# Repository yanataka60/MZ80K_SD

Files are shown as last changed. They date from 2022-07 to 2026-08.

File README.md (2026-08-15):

# MZ-80シリーズにSD-Cardとのロード、セーブ機能を

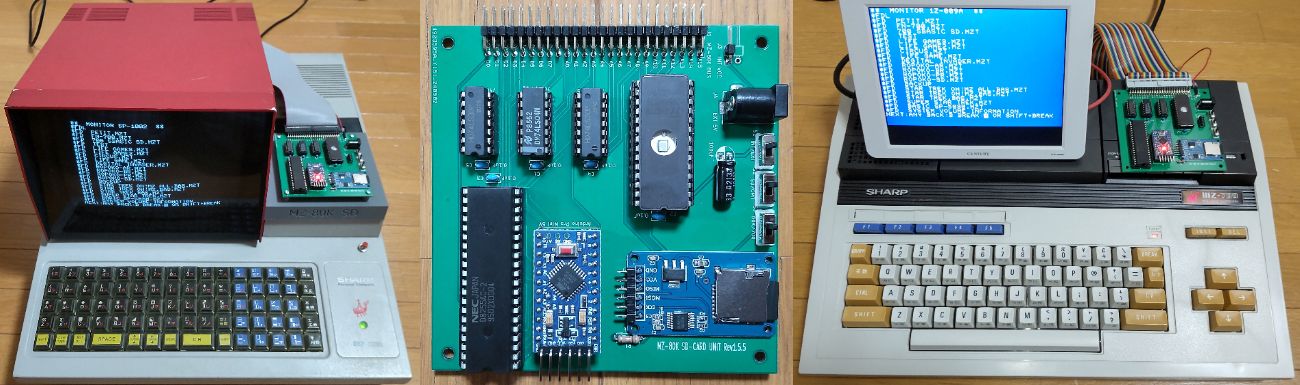
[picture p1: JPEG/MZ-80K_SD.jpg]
MZ-80K_SD


　ROMをF000Hに置くことでMZ-80シリーズにフロッピーディスク装置を外付けした際に起動するためのFDコマンドを利用できますが、フロッピーディスク装置の代わりにSD-CARDを繋いでしまおうというものです。

#### 　2025.7.31追記 MZ-80K、MZ-80K2、MZ-80K2E、MZ-80C、MZ-1200、MZ-700で動作しますが、MZ-700はRAMとの切替動作をサポートしたMZ-700_SDもあります。

　アダプタを繋ぐだけでもBASIC SP-5030が約4秒で起動できるようになるなどアプリケーションランチャーとして便利に使えますが、MONITOR SP-1002にパッチをあてることでBASIC SP-5030はもちろん、ほとんどのMZ-80KアプリケーションがSD-CARD対応となります。

### 本体ROMをパッチを当てたMONITOR SP-1002に交換しなくてもアプリケーションからのロード、セーブをSD対応とさせるパッチあてWindows用ツール「CMT2SD_CHECK」を公開しました。(2022.6.29)
### 詳細は、CMT2SD_CHECKフォルダ中のREADME.mdを参照してください。

　MZ-700もMZ-80K用アプリケーションについては同様にSD-CARD対応となりますが、標準添付のS-BASIC、Hu-BASICともMONITOR 1Z-009A、1Z-009BのCMTルーチンを利用していないためMONITOR 1Z-009A、1Z-009BにパッチをあてただけではSD-CARD対応となりません。

　S-BASICについてはパッチを当てることでSD-CARD対応となりますが、Hu-BASICは未対応です。

　基本的にはMZ-700ではMZ-80K互換機として利用できると考えてください。

　また、MZ-700もFDxコマンドは機能しますのでMZ-700用アプリケーションランチャーとして使えますが、MZ-80K対応とうたっていない64KオールRAMを前提としているMZ-700用アプリケーションはロードできない可能性があります。

　MZ-700+MZ-80K_SDでMZ-700用アプリケーションを実行したときにMZ-80K_SDのROMとMZ-700本体のRAMが衝突しないよう「ROM切り離しスイッチ」を取り入れましたが、これを自動で行うMZ-700_SD基板も公開しています。ただし、MZ-700_SDを作成するにはGAL16V8の入手が必要です。

　なお、一部のMZ-80K用ソフトはMZ-700で実行するにあたって、0h!MZ別冊 ADVANCED MZ-700に掲載されているSP-1002のMZ-700対応版 NZ-700が必要となるものがあります。

https://github.com/yanataka60/MZ-700_SD

#### 注）

　一応安定動作を確認していますが、SAVE動作によりSD-CARDに保存されたデータファイルの消失等考えられますのでファイルのバックアップをお願いします。

　Arduino、ROMへ書き込むための機器が別途必要となります。

### (2026.8.13追記)すねいるさんのBARYONに対応するためArduinoプログラムを更新しました。また、ROMプログラムも合わせて更新することで多段ロードにも対応します。

### 多段ロードの詳細については後述「BARYON対応」「多段ロード対応」を参照してください。

BARYON対応:https://github.com/yanataka60/MZ80K_SD#baryon%E5%AF%BE%E5%BF%9C2026813

多段ロード対応:https://github.com/yanataka60/MZ80K_SD#%E5%A4%9A%E6%AE%B5%E3%83%AD%E3%83%BC%E3%83%89%E5%AF%BE%E5%BF%9C2026813

## 回路図
　KiCadフォルダ内のMZ80K_SD.pdf参照

[回路図](https://github.com/yanataka60/MZ80K_SD/blob/main/KiCad/MZ80k_SD/MZ80K_SD.pdf)
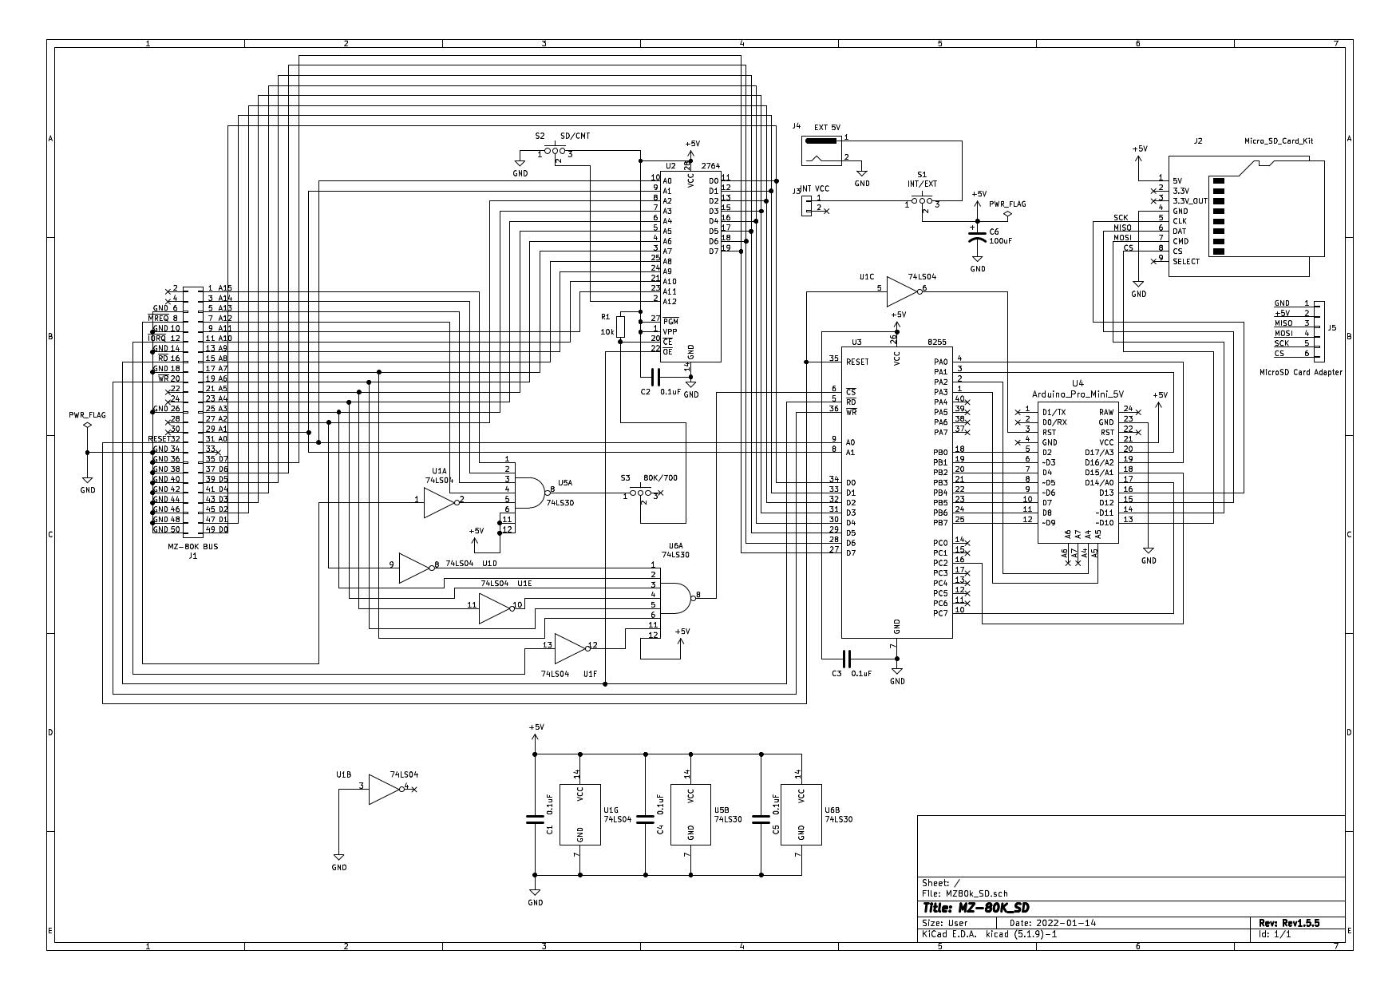
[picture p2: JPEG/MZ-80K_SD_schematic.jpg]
回路図


## 部品
|番号|品名|数量|備考|
| --- | --- | --- | --- |
|U1|74LS04|1||
|U2|2764又は28C64|1|ROMの相性については後述|
|U3|8255|1||
|U4|Arduino_Pro_Mini_5V|1|Atmega328版を使用 168版は不可。(注1)|
|U5 U6|74LS30|2||
||J2、J5のいづれか|||
|J2|Micro SD Card Kit又は同等品|1|秋月電子通商 AE-microSD-LLCNV (注2) (注3)|
|J5|MicroSD Card Adapter|1|Arduino等に使われる5V電源に対応したもの (注3)|
|C1-C5|積層セラミックコンデンサ 0.1uF|5||
|C6|電解コンデンサ 16v100uF|1||
|S1 S2|3Pスライドスイッチ|2|秋月電子通商 SS12D01G4など|
|S3|3Pスライドスイッチ|1|MZ-700で使わなければ80K側固定のジャンパでも可|
|R1|カーボン抵抗 10kΩ|1|S3を使わずに80K側固定でジャンパするなら不要|
|J4|DCジャック|1||
|J3|コネクタ 2Pin|1|ピンヘッダで代用するときはGNDと間違えないよう1Pinで5Vだけにしたほうが良い|
|J1|50Pinコネクタ|1||
||50Pinケーブル|1||
||ピンヘッダ|2Pin分|Arduino_Pro_MiniにはA4、A5用のピンヘッダが付いていないため別途調達が必要です 秋月電子通商 PH-1x40SGなど|
||本体内から5Vを取る場合、ケーブル少々|||
||本体ROMにパッチをあてる場合、27C32等を2532ソケットに差すためのアダプタ|||
||ピンソケット(任意)|26Pin分|Arduino_Pro_Miniを取り外し可能としたい場合に調達します 秋月電子通商 FHU-1x42SGなど|

　　　注1)Arduino Pro MiniはA4、A5ピンも使っています。

　　　注2)秋月電子通商　AE-microSD-LLCNVのJ1ジャンパはショートしてください。

　　　注3)J2又はJ5のどちらかを選択して取り付けてください。

### MicroSD Card Adapterを使う
J5に取り付けます。

MicroSD Card Adapterについているピンヘッダを除去してハンダ付けするのが一番確実ですが、J5の穴にMicroSD Card Adapterをぴったりと押しつけ、裏から多めにハンダを流し込むことでハンダ付けをする方法もあります。なお、この方法の時にはしっかりハンダ付けが出来たかテスターで導通を確認しておいた方が安心です。

ハンダ付けに自信のない方はJ2の秋月電子通商　AE-microSD-LLCNVをお使いください。AE-microSD-LLCNVならパワーLED、アクセスLEDが付いています。

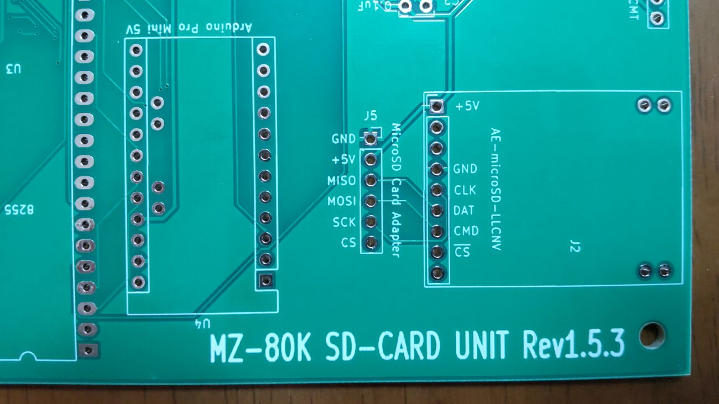
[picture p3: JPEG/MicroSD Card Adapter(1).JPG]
MicroSD Card Adapter1


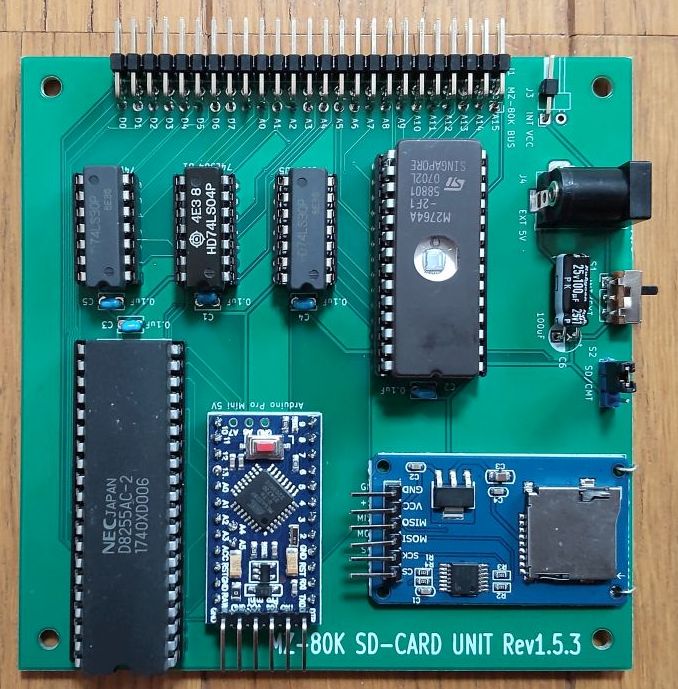
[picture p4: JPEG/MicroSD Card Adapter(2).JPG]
MicroSD Card Adapter2


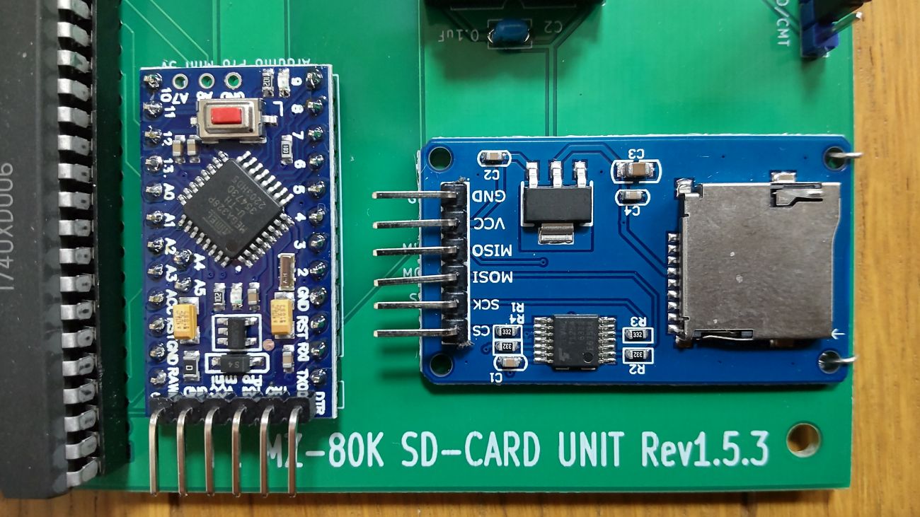
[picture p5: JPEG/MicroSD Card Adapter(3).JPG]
MicroSD Card Adapter3


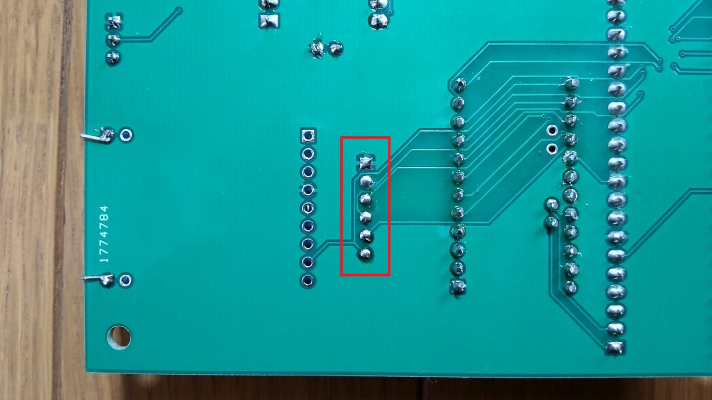
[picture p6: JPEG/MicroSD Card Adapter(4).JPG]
MicroSD Card Adapter4


## ROMプログラムについて
　Z80フォルダ内にFD_rom1.bin、FD_rom2.bin、FD_rom.binと3つありますが、SD-CARDを利用するためのプログラムFD_rom1.bin(28C64の下位に配置)、MONITORをCMT利用に戻すためのプログラムFD_rom2.bin(28C64の上位に配置)、2つを合わせたプログラムFD_rom.binとなっています。

　ROMライター(TL866II Plus等)を使って2764又は28C64にFD_rom.binを書き込んでください。

　28C64にFD_rom.binを書き込むことでスライドスイッチによりSDとCMTを切り替えられるようにしてあります。

　ただし、稼働中に切り替えるとタイミングによってはMZ-80Kが暴走する時があります。基本的には電源を切って切り替えてください。

　また、FD_rom2の領域には4023Byte分の空きエリアがあります。自由に使っていただいて構いません。

　なお、MZ-700でMONITOR 1Z-009A、1Z-009BにMZ-80K_SD用のパッチをあてた状態でもCMT側に切り替えれば紅茶羊羹さんの「MZ⇔PC間でデータを転送する（USB版）」が問題なく使用できます。

## ROMの相性
　すべての状況をテストできたわけではないのですが、ROMの個体によっては相性があるのではないかとの報告があります。

　特に問題なく動いているROMと動かない個体の例が報告されているROMを以下に列挙します。

　これからROMを調達される方はなるべく「特に問題なく動いているROM」を調達したほうが無難だと思われます。

|特に問題なく動いているROM|
| ----------------------- |
|AT28C64B                 |
|CAT28C64BP               |
|M2764A                   |

|動かない個体の例が報告されているROM|
| --------------------------------- |
|HN484764G                          |
|M27C64A                            |
|TMM2764D                           |
|TMS2764                            |
|D28C64ACZ                          |

## Arduinoプログラム
　Arduino IDEを使ってArduinoフォルダ内のMZ-80K_SD.inoを書き込みます。

　SdFatライブラリを使用していますのでArduino IDEメニューのライブラリの管理からライブラリマネージャを立ち上げて「SdFat」をインストールしてください。

　「SdFat」で検索すれば見つかります。「SdFat」と「SdFat - Adafruit Fork」が見つかりますが「SdFat」のほうを使っています。

注)Arduinoを基板に直付けしている場合、Arduinoプログラムを書き込むときは、MZ-80K本体とは接続を外し、74LS04を外したうえで書き込んでください。

## MZ-80Kとの接続
　回路図J1のピン番号とMZ-80K外部拡張端子のピン番号は一致していません。ピン配置は一致していますのでJPGフォルダにある「Rev1.5.1+MZ-80K Series(6).JPG」を参考にフラットケーブルで接続してください。

　MZ-700の外部拡張端子はMZ-80Kとピン配置は同じですが、ピンコネクタではなく、カードエッジコネクタです。

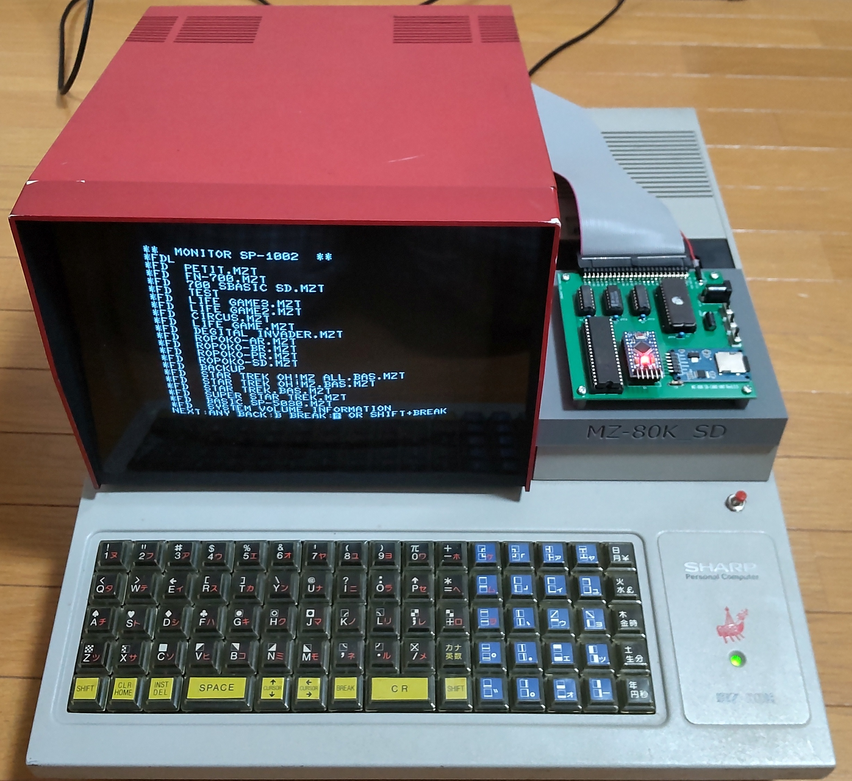
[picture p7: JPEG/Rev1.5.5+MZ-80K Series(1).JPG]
接続1


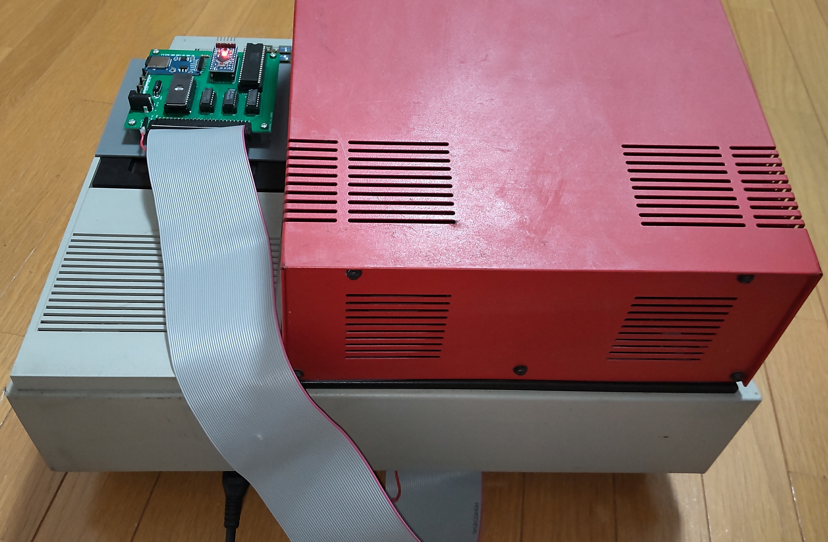
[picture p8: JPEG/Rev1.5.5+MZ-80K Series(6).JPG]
接続2


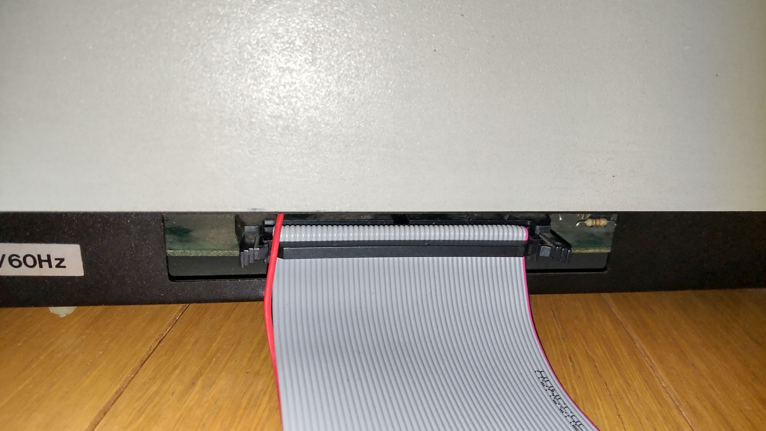
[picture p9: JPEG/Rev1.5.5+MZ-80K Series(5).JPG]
接続3


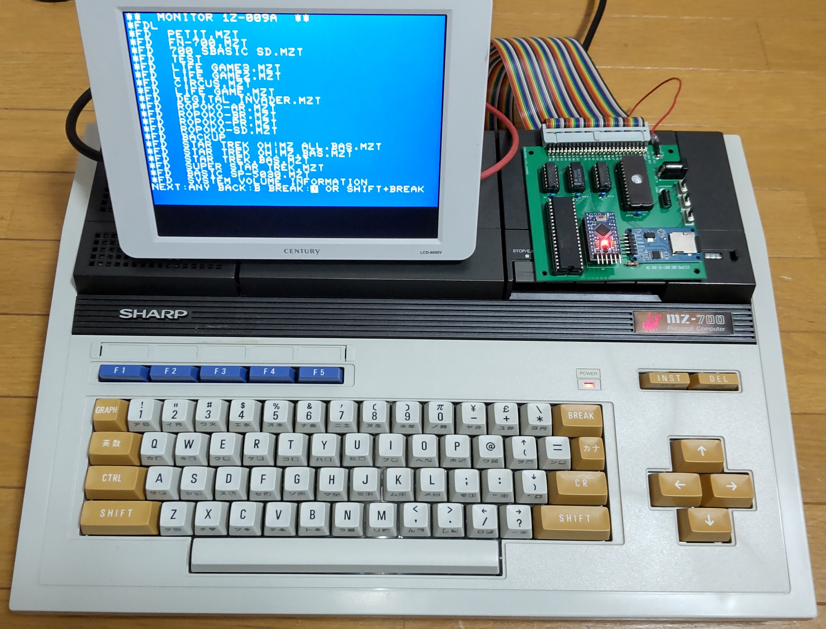
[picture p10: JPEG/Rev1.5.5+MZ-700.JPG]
接続4


## 電源
　MZ-80Kのバスには+5Vが出ていないため、最初はDCジャックから外部電源を供給するつもりだったのですが、本体と電源が一緒のほうが扱いが楽そうだったので本体から+5Vを引き出して供給する用のコネクタと二通りを用意しています。

　MZ-80K内部から5Vを取得するには、27C32等を2532ソケットに差すためのアダプタから引っ張ってくるのが簡単だと思います。

## MONITOR ROMの差し替え
　MONITOR SP-1002、MONITOR 1Z-009A、1Z-009Bとも以下のパッチをあててください。

　0437 : D5 → C3

　0438 : C5 → 04

　0439 : E5 → F0

　0476 : D5 → C3

　0477 : C5 → 07

　0478 : E5 → F0

　04D9 : D5 → C3

　04DA : C5 → 0A

　04DB : E5 → F0

　04F9 : D5 → C3

　04FA : C5 → 0D

　04FB : E5 → F0

　0589 : D5 → C3

　058A : C5 → 10

　058B : E5 → F0

　MZ-700 MONITOR 1Z-009A、1Z-009Bについては、RAMにコピーしたMONITORにパッチを当てることでパッチを当てたROMに差し替えなくても済むように「FT.MZT」を作成しました。

　「FT.MZT」をSD-CARDのルートに置き、FD FT[CR]を実行することでRAM MONITORに制御が移ります。

　「FT.MZT」と同等の動作をするFDZコマンドを新設しました。FDZコマンドを使えば「FT.MZT」は必要ありません。

　また、紅茶羊羹さんの「MZ⇔PC間でデータを転送する（USB版）」でMZTrans用パッチをMONITOR 1Z-009A、1Z-009Bに当てているとFコマンドが使えないので以下のパッチを当てることで'#'コマンドをつぶして'F'コマンドを復活させます。

　00D2 : 23 → 46

　00D4 : 86 → 21

　紅茶羊羹さん作成の「TR.MZT」をSD-CARDのルートに置き、「FD TR」を実行することでMZTransを使う方法もあります。

## BASIC SP-5030 バージョン違い

　BASIC SP-5030には、旧・新・VER1.0Aの３種類のバージョンがあるそうで、そのうち新・VER1.0Aの二つはパッチをあてる必要があります。以下のアドレスが4049H、4069Hを指している場合には新・VER1.0Aのどちらかですので以下のように修正する必要があります。

アドレスはMZTファイルのアドレスです。実アドレスは()内

　18C5(1845) : 49 → 27

　18C6(1846) : 40 → 00

　1939(18B9) : 69 → 2A

　193A(18BA) : 40 → 00

　19EA(196A) : 69 → 2A

　19EB(196B) : 40 → 00

　1AE0(1A60) : 69 → 2A

　1AE1(1A60) : 40 → 00

## SD-CARD
　出来れば8GB以下のSDカードを用意してください。

　ArduinoのSdFatライブラリは、SD規格(最大2GB)、SDHC規格(2GB～32GB)に対応していますが、SDXC規格(32GB～2TB)には対応していません。

　また、SDHC規格のSDカードであっても32GB、16GBは相性により動作しないものがあるようです。

　FAT16又はFAT32が認識できます。NTFSは認識できません。

　ルートに置かれたMZTファイルのみ認識できます。(MZT以外のファイル、フォルダも表示されますがLOAD実行の対象になりません)

　ファイル名は「.MZT」を除いて32文字まで、ただし半角カタカナ、及び一部の記号はArduinoが認識しないので使えません。パソコンでファイル名を付けるときはアルファベット、数字および空白でファイル名をつけてください。

## 操作方法
　MONITORコマンド入力待ちから以下のコマンドが利用できます。

　なお、MZ-700のフロッピーディスク装置起動コマンドは本来'F'の一文字ですが、操作方法としては'FD'に統一しました。

　以下、SD-CARD内のファイルに付けられるファイル名をDOSファイル名、MZT形式ファイルのインフォメーションブロック内ファイル名をIBFファイル名とします。

### FD[CR]
　FDのみでDOSファイル名「0000.MZT」がLOAD及び実行されます。

　「0000.MZT」は、パソコンでBASIC SP-5030等をリネームコピーして作成しても大丈夫ですが、FDAコマンドから作ることもできます。

### FD　DOSファイル名[CR]
　DOSファイル名で指定したバイナリファイルをLOADして実行します。

　「.MZT」は省略可能です。

　MONITORのLOADコマンドの代替として使えます。なお、LOADコマンドも使えますが、アプリケーションからのLOADと同じ扱いになります。

例)

FD　TEST[CR]

### FD/DOSファイル名[CR] 又は FD/　DOSファイル名[CR]
　DOSファイル名で指定したバイナリファイルをLOADします。実行はしません。

　「.MZT」は省略可能です。

例)

FD/TEST[CR]

FD/　TEST[CR]

### FDL[CR]
　SD-CARDルートディレクトリにあるファイルの一覧を表示します。20件表示したところで指示待ちになるので打ち切るならSHIFT+BREAK又は↑を入力すると打ち切られ、Bキーで前の20件に戻ります。それ以外のキーで次の20件を表示します。

　行頭に「*FD」を付加して表示してあるので実行したいファイルにカーソルキーを合わせて[CR]キーを押すだけでLOAD、実行が可能です。

　表示される順番は、登録順となりファイル名アルファベッド順などのソートした順で表示することはできません。

### FDL　x[CR]
ファイル名がxで始まるファイルの一覧を表示します。20件表示したところで指示待ちになるので打ち切るならSHIFT+BREAK又は↑を入力すると打ち切られ、Bキーで前の20件に戻ります。それ以外のキーで次の20件を表示します。

xはMZのキーボードから入力可能な32文字までの文字列です。(数字、記号、アルファベット)

例)

FDL S[CR]

FDL SP[CR]

FDL BASIC S[CR]

### FDA　DOSファイル名[CR]
　DOSファイル名で指定したファイルを「0000.MZT」という名前でリネームコピーします。

　FDLコマンドで表示されたファイル名をカーソルで選択し、行頭の「*FD」に「A」だけ付加して[CR]キーを押せば簡単です。

### FDS　SAVE開始アドレス　SAVE終了アドレス　実行開始アドレス　DOSファイル名[CR]
　SAVE開始アドレスからSAVE終了アドレスまでをDOSファイル名でSAVEします。

　SAVE開始アドレス、SAVE終了アドレス、実行開始アドレスは16進数4桁で指定します。DOSファイル名の「.MZT」は省略可能です。

例)

FDS　1200　2FFF　1200　TEST[CR]

### FDC　DOSファイル名[CR]
　DOSファイル名で指定したファイルをコピーします。

　FDLコマンドで表示されたファイル名をカーソルで選択し、行頭の「*FD」に「C」だけ付加して[CR]キーを押せば簡単です。

　DOSファイル名を入力し、[CR]キーを押すと「NEW NAME:」と聞いてくるので新しいDOSファイル名を入力して[CR]キーを押します。

　新しいDOSファイル名に既にあるDOSファイル名を指定するとコピーせずに中断します。

例)

FDC　TEST[CR]

NEW NAME:TEST2[CR]

### FDR　DOSファイル名[CR]
　DOSファイル名で指定したファイルをリネームします。

　FDLコマンドで表示されたファイル名をカーソルで選択し、行頭の「*FD」に「R」だけ付加して[CR]キーを押せば簡単です。

　DOSファイル名を入力し、[CR]キーを押すと「NEW NAME:」と聞いてくるので新しいDOSファイル名を入力して[CR]キーを押します。

　新しいDOSファイル名に既にあるDOSファイル名を指定するとリネームせずに中断します。

例)

FDR　TEST[CR]

NEW NAME:TEST2[CR]

### FDD　DOSファイル名[CR]
　DOSファイル名で指定したファイルを削除します。

　FDLコマンドで表示されたファイル名をカーソルで選択し、行頭の「*FD」に「D」だけ付加して[CR]キーを押せば簡単です。

　DOSファイル名を入力し、[CR]キーを押すと「FILE DELETE?(Y:OK ELSE:CANSEL)」と聞いてくるのでYを押せば削除されます。Y以外のキーを押すとキャンセルとなります。

### FDP　DOSファイル名[CR]
　DOSファイル名で指定したファイルの内容をDUMPします。

　FDLコマンドで表示されたファイル名をカーソルで選択し、行頭の「*FD」に「P」だけ付加して[CR]キーを押せば簡単です。

　DOSファイル名を入力し、[CR]キーを押すとファイルの内容を128Byteを一画面として表示します。

　一画面表示したところで「NEXT:ANY BACK:B BREAK:SHIFT+BREAK」と表示して指示待ちとなるのでBで前の128Byteを表示、SHIFT+BREAKで中止、それ以外のキーで次の128Byteの表示となります。

　ファイルサイズが128Byteで割り切れない場合には最後のページは128Byteに揃うまで00Hで埋められます。

　ファイル内容を書き換えることはできません。

### FDM　開始アドレス[CR]
　開始アドレスからMZ-80Kのメモリ内容を128Byteを一画面として表示します。

　一画面表示したところで「NEXT:ANY BACK:B BREAK:SHIFT+BREAK」と表示して指示待ちとなるのでBで前の128Byteを表示、SHIFT+BREAKで中止、それ以外のキーで次の128Byteの表示となります。

　一画面表示している途中でもSHIFT+BREAKでいつでも中止できます。

### FDW　開始アドレス　1Byte(16進2桁)データ[CR]
　開始アドレスから16進2桁データをMZ-80Kのメモリに書き込みます。

　開始アドレスに続けて16進2桁で書き込むデータを記述し[CR]キーを押します。データの区切りの空白は無視しますのであってもなくても構いません。

　16進2桁のByteデータは一行に収まる範囲なら何Byte分を続けても構いません。

　一行入力して[CR]キーを押すとデータが書き込まれ、次のアドレスが表示されるので続けてデータを入力していけます。

　また、アドレスを修正すれば戻って修正や離れたアドレスにデータを書き込むことも可能です。

　データの書き込みを止めるときは表示されたアドレスにデータを書かずに[CR]キーを押します。

　16進数以外を入力して[CR]キーを押した場合には16進数以外を入力した直前までの有効なデータを書き込み次のアドレスを表示します。

例)

*FDW　1200　01　02　03　04　05　06　07　08[CR]

*FDW　1200　0102030405060708[CR]

*FDW　1200[CR]　(止めるとき)

*FDW　1200　12　34　5/[CR]　(12　34まで書き込まれます)

### FDZ[CR]
　【MZ-700専用】MZ-700用に作成した「FT.MZT」と同等の動きをします。 MONITOR 1Z-009A又は1Z-009Bを裏RAMにコピーしたうえでパッチを当てた後、裏RAM上のMONITORがスタートします。

　MZ-80Kで実行してしまった場合には、RESET動作となります。

### FDU[CR]
　【MZ-700専用、裏RAM MONITORで運用中にRESETした場合に限る】裏RAMに切り替え裏RAMのMONITORをスタートさせます。

　注）裏RAMにMONITORが無い状態で実行すると暴走します。

　MZ-80Kで実行してしまった場合には、RESET動作となります。

### アプリケーションからのLOAD
　L、LOAD等アプリケーションが指定したコマンドの後ろにはIBFファイル名を指定可となっていますが、指定せずにL、LOAD等のコマンドのみで[CR]キーを押します。

　CMTの場合にはここでPLAYボタンを押すよう指示が出るところですが、「DOS FILE:」と表示して行入力待ちになっていますのでDOSファイル名を入力して[CR]キーを押します。この時、「.MZT」の入力は省略できます。

　DOSファイル名は「.MZT」を除いて32文字まで、ただし半角カタカナ、及び一部の記号はArduinoが認識しないので使えません。パソコンでファイル名を付けるときはアルファベット、数字および空白でファイル名をつけてください。

例)BASIC SP-5030では

× LOAD "TEST"[CR]

○ LOAD[CR]

　DOS FILE:TEST[CR]

○ LOAD[CR]

　DOS FILE:TEST.MZT[CR]

** 参考 **

　S-OS SWORDでの運用に当たっては起動直後に「DV S:」としてデバイスを各SYSTEMデバイスとしてください。

　FUZZY BASICだけかもしれませんが共通フォーマットデバイスのままだとLOADコマンドでIBFファイル名の省略ができませんでした。

#### LOAD時の特殊コマンド
　「DOS FILE:」と表示して行入力待ちになったときに以下の特殊コマンドが使用可能です。

##### *FDL[CR]
##### *FDL x[CR]
　MONITORコマンド入力待ちからのFDL、FDL xと全く同等のファイル一覧機能が使えます。

　検索結果の行頭には「DOS FILE:」を付加して表示してあるのでLOADしたいファイルにカーソルキーを合わせて[CR]キーを押すだけでLOADが可能です。

　「*FDL」で検索、カーソルで選んで読み込もうとした場合に「DOS FILE:」に戻ってしまうアプリケーションがありますが、再度カーソルを合わせて[CR]すれば読み込めます。

### アプリケーションからのSAVE
　CMTの時と同様にアプリケーションの指定する入力方法、ルールでファイル名等を入力して保存してください。

　ただし、半角カタカナはArduinoが認識できないため、使用できません。アルファベット、数字および空白で指定してください。

　SAVE時は、入力したファイル名がIBFファイル名、DOSファイル名の両方に適用されます。

　DOSファイル名としての「.MZT」は自動的に付加されます。

例)BASIC SP-5030では

○ SAVE "TEST"[CR]

## 操作上の注意
　~~「SD-CARD INITIALIZE ERROR」と表示されたときは、SD-CARDをいったん抜き再挿入したうえでArduinoをリセットしてください。~~

　~~SD-CARDにアクセスしていない時に電源が入ったままで SD-CARDを抜いた後、再挿入しSD-CARDにアクセスすると「SD-CARD INITIALIZE ERROR」となる場合があります。再挿入した場合にはSD-CARDにアクセスする前にArduinoを必ずリセットしてください。~~

　~~SD-CARDの抜き差しは電源を切った状態で行うほうがより確実です。~~

　(2024.3.10) SD-CARDにアクセスしていない時に電源が入ったままでSD-CARDを抜くと再度SD-CARDを挿入してもSD-CARDにアクセスできない問題を解消しました。(Arduinoを最新版に書き換えてください)

　再度SD-CARDを挿入した後、FDL、LOAD、SAVE等でSD-CARDに3回ほどアクセスすれば復旧します。

　SD-CARDへのセーブ時にDOSファイル名を指定せずに[CR]を押下してしまった場合、「.MZT」というDOSファイルが作成されてしまいます。この「.MZT」はアプリケーションからLOADする時にDOSファイル名を指定せずに[CR]を押下した場合に読み込まれることで不測の動作を起こす原因になりますので作成された場合には削除しておく方が無難です。

　なお、「.MZT」は現在FDR及びFDDコマンドでは認識できませんので、Windowsパソコンから消去してください。

## SD-CARDに読み書きできるかを試した結果

　読み書き出来たもの(アルファベット順)

　　BASE-80 Ver35【I/O 1981年4月号】

　　BASIC SP-5030(パッチあて必要なバージョンあり)

　　CAP-Xインタプリタ【I/O 1980年5月号】

　　EDASM V1.2B【Oh!MZ 1985年1月号】

　　FORM VER1.0(注3)【I/O 1980年6月号】

　　FORTRAN-MZ V.1【I/O 1981年1月号】

　　GAME-MZ80K V.1(注1)【ASCII 1979年10月号】

　　HU-BASIC V1.3

　　KM-BASIC ver 0.8.3-beta(注2)

　　LSIアセンブラ(注1)【【ASCII 1979年11月号】

　　M-FORTH/MZ V1.1(注1)【I/O 1981年3月号】

　　micro PASCAL-MZ VER 2.2【ASCII 1980年6月号】

　　MONIOS【月刊マイコン 1982年2月号】

　　PALL【I/O 1979年12月号】

　　S-OS SWORD(S-OS用アプリ含む)【Oh!MZ 1986年2月号】【再掲載 Oh!MZ 1987年3月号】

　　SELF RELOCATABLE DEBUGGER【I/O 1980年11月号】

　　SP-2101 Z80 ASSEMBLER

　　SP-2201 TEXT EDITOR

　　SP-2301 RELOCATE LOADER

　　SP-2401 SYMB DEBUGGER

　　TL/1(注1)(注3)【ASCII 1981年5月号】

　　TTL VERSION 1.1【Oh!MZ 1984年10月号】

　　WICS INTERPRETER VER 1.1(注3)【I/O 1981年10月号】

　　8080用テキスト・エディタ＆アセンブラ【I/O 1980年9月号】

　　マシン語モニタ【I/O 1979年10月号】【I/O合本 MZ-80活用研究】

　　整数型ベーシックコンパイラー for MZ-80K/C, MZ-1200(注1)(注3)【諏訪工房】

注1)このアプリケーションはMZ-700非対応です。MZ-700で動かすには、0h!MZ別冊 ADVANCED MZ-700に掲載されているSP-1002のMZ-700対応版 NZ-700が必要です。NZ-700にSP-1002と同じようにMZ-80K_SDのパッチをあてることでMZ-700でも同様にLOAD、SAVEが可能となります。

注2)SAVEコマンドでファイルネームは指定できないようです。SAVE[CR]で「KMB-FILE VER 1.0」のファイルネームで保存されました。

注3)LOADコマンドから「*FDL」で検索、カーソルで選んで読み込もうとした場合に「DOS FILE:」に戻ってしまいますが、再度カーソルを合わせて[CR]すれば読み込めます。

　読み書き出来なかったもの

　　EDAS FOR MZ-1200 VER 1.2【I/O 1982年11月号】

　　EXIT MONITOR【ASCII 1981年6月号】

## MZ700用プログラムで起動確認したもの
　　S-BASIC 1Z-007B(LOAD、SAVEもSD対応となるパッチを公開しました)

　　S-OS SWORD(MZ-700用SWORDでSD-CARD運用するにはMONITOR-ROMの書き換えが必要です。MONITOR-ROMを書き換えずに「FT.MZT」又はFDZコマンドを実行しても起動後のLOAD、SAVEはCMTとなります)

　　HUBASIC VERSION 2.0A(起動後のLOAD、SAVEはCMT)

　　tiny XEVIOUS mz-700

　　タイムシークレット(すべてのプログラムを別ファイルとして保存が必要)

　　タイムトンネル(すべてのプログラムを別ファイルとして保存が必要)

　　TS-700(「I/O別冊 WICS・BASEプログラム集」掲載、TS-700フォルダ参照)

　　SuperBASE-700(「I/O別冊 WICS・BASEプログラム集」掲載、TS-700フォルダ参照)

　　WICSインタプリタ、コンパイラ(「I/O別冊 WICS・BASEプログラム集」掲載、TS-700フォルダ参照)

なお、起動確認していないアプリケーションでも起動だけであればFDコマンドで起動できる可能性があります。

## 自作アプリケーションでMZ-80K_SDからLOADするDOSファイル名を指定したい場合
　MZ-80K用自作アプリケーションでMZ-80K_SDからデータ・機械語プログラム等のバイナリデータをLOADする処理を追加したい場合にはF00Ah(MLHED)をコールしてDOSファイル名を入力した後、F00Dh(MLDAT)をコールしてデータをロードとなり、DOSファイル名をアプリケーションの中で指定しておくことが出来ません。

　そこで以下の機械語をアプリケーションに組み込み、コールすることでアプリケーション内でDOSファイル名を指定することが可能です。

　その後、F00DHをコールすればSDからLOADが実行されます。

|コード|
| ------------ |
|MLHED:　　LD　　　DE,FNAME|
|　　　　　DI|
|　　　　　PUSH　　DE|
|　　　　　PUSH　　BC|
|　　　　　PUSH　　HL|
|　　　　　CALL　　F082H|
|　　　　　PUSH　　DE|
|　　　　　XOR　　　A|
|　　　　　LD　　　DE,0000H|
|　　　　　CALL　　0033H|
|　　　　　POP　　　DE|
|　　　　　JP　　　F85BH|
|FNAME:|
|　　　　　DB　　　'TEST',0DH|

#### BASIC SP-5030のプログラム中でMZ-80K_SDからLOADするDOSファイル名を指定したい場合
　BASIC SP-5030で使うときは以下の機械語を適当なアドレスに配置し、BASICから呼び出します。

　わずかな機械語ですのでBASICプログラム中にDATA文にしておき、LIMIT文で機械語領域を確保、READ文で読み込み、POKE文でメモリに書き込むようにすれば手軽です。

|コード|
| ------------ |
|MLHED:　　DI|
|　　　　　PUSH　　DE|
|　　　　　PUSH　　BC|
|　　　　　PUSH　　HL|
|　　　　　CALL　　F082H|
|　　　　　PUSH　　DE|
|　　　　　XOR　　　A|
|　　　　　LD　　　DE,0000H|
|　　　　　CALL　　0033H|
|　　　　　POP　　　DE|
|　　　　　JP　　　F85BH|

DATA 243,213,197,229,205,130,240,213,175,017,000,000,205,051,000,209

DATA 195,091,248

##### BASIC SP-5030からの呼び出し

|コード|備考|
| --- | --- |
|G＄="TEST"|DOSファイル名を表す文字列を文字列変数に代入|
|USR(＄C000,G＄)|機械語を配置したアドレスとDOSファイル名を表す文字列を代入した文字列変数を値としてUSR関数を実行(SP-5030の場合文字列関数に代入された文字列の最後に0Dhが入ってます)|
|USR(＄F00D)|SDからデータをLOAD|

#### MZ-700でDOSファイル名を指定したい場合
　MONITOR 1Z-009A(B)上で動くアプリケーションであればF000hからのROMにバンク切替(OUT (E3h),A)することを考慮すればMZ-80Kと同じように機械語をコールすることで指定できるようになるはずです。

　S-BASIC上でDOSファイル名を指定するにはバンク切替の他、文字列関数に代入された文字列の最後が00hで終わっていること、インフォメーションブロック(IFB)の位置もMONITOR 1Z-009A(B)とは違う等の差異を解決できる方以外はハードルが高いかもしれません。

## 専用トレイ
　カセット部に被せて使うMZ-80K_SD用トレイを公開しました。

https://yanataka.booth.pm/items/6058283

　MZ-1200用はこちらです。

https://yanataka.booth.pm/items/6069703

## BARYON対応(2026.8.13)
　MZ-700本体ROMにMZ-80K_SD(MZ-700_SD)用パッチを当てていなければBARYONの3分割mztファイル(baryon-1.mzt,baryon-2.mzt,baryon-3.mzt)で問題なく起動しますが、MZ-700本体ROMにMZ-80K_SD(MZ-700_SD)用パッチを当てていると異常動作により起動できません。

　これに対応するため、Arduinoプログラムを更新しましたので書き換えてください。

　これによりBARYON 3分割mztファイル(baryon-1.mzt,baryon-2.mzt,baryon-3.mzt)が正常に起動するようになります。

　また3つのmztファイルを連結したものとして提供されているbaryon.mztを「baryon$.mzt」とファイルネームの最後に「$」を付けることで起動できるようになりました。

## 多段ロード対応(2026.8.13)
　Arduino、ROMの両方を更新することで次の４種類の多段ロードに対応します。

　ただし、IPL.ROM内のCMTサービスルーチンをコールしていることが条件です。２段目以降のLOADにサービスルーチンをコールせず、独自プログラムで読み込むプログラムには対応できません。

### ①複数mztファイル連続読み込み
　連続して読み込ませたいmztファイルのファイル名の最後に#n(n=1～9)連続する数字を付加します。

例)

hoge#1.mzt

hoge#2.mzt

hoge#3.mzt

### ②連結mzt
　連続して読み込ませたいmztファイルを単純にマージしたmztファイルです。ファイル名の最後に#を付加してください。

例)

hoge#.mzt

### ③連続データブロック形式(IFB、DATA、DATA…)[ダミーヘッダ無]
　インフォーメションブロックに続き、複数のデータブロックが配置されたmztファイルです。実機CMTファイルで多段ロードに使用されることがある形式でダミーヘッダはありません。ファイル名に制限はありません。

例)

hoge.mzt

### ④連続データブロック形式(IFB、DATA、(IFB)、DATA…)[ダミーヘッダ有]
　インフォーメションブロックに続き、複数のデータブロックが配置されたmztファイルです。③の形式ですが、IFBがないと動作しないエミュレータ用にダミーヘッダが付加されたものです。③と区別するためにファイル名の最後に$を付加してください。

例)

hoge$.mzt

## 謝辞
　基板の作成に当たり以下のデータを使わせていただきました。ありがとうございました。

　Arduino Pro Mini

　　https://github.com/g200kg/kicad-lib-arduino

　AE-microSD-LLCNV

　　https://github.com/kuninet/PC-8001-SD-8kRAM

　MZ-700への対応に当たっては、紅茶羊羹様の「MZ⇔PC間でデータを転送する（USB版）」が非常に参考になりました。ありがとうございました。

　不安定動作の解消に以下の皆様にご協力とご助言をいただきました。ありがとうございました。(アルファベット順)

　　EIJ様

　　hlide fremen様

　　junk_suga様

　　retrogamer128様

　Arduino等に使われる5V電源に対応したMicroSD Card Adapterを使って作られた事例をご報告いただきました。ありがとうございました。

　　𝕊𝕖ñ𝕠𝕣 𝔼𝕤𝕥𝕖𝕓𝕒𝕟様

## 追記
2021.12.12

　MZ-700をMZ-80Kの代わりとして使うだけならNZ-700を最初に起動すればパッチを当てたROMを焼かなくてもいいんだと気づきました。FDコマンドでNZ-700が起動するようにすればMZ-700のほうがハードルが低いかもしれません。

2021.12.12

　MZ-700用に「FT.MZT」を作成しました。

2021.12.13

　KiCad\MZ80k_SDフォルダの回路図MZ80K_SD.pdfをRev1.1に更新

2021.12.13

　MZ-80KのS-OS SWORDでアプリケーションをLOADしようとしたとき、最初の一回だけはなぜかインフォメーションブロックの読み込みで止まってしまい、継続するためにはキーを一回押す必要がある原因は、FLGETのDEBUGにMZ-700用の修正もしてしまっていたせいでした。元に戻したところ無事解消。

2021.12.14

　S-BASICについてSD-CARD対応とするパッチを公開しました。

2021.12.18 2021.12.19 2021.12.21

　(MZ-80Kの電源状況によっては内部電源では動作不安定になることもあるようです。不安定な挙動がある場合には外部電源を試してください。)

　昨日追記した挙動不安定は電源のせいではなく、28C64がハズレあるいは個体差によりブラウン管の磁気の影響を受けていたためでした。

　28C64に個体差があるとは思われますが、それを吸収すべきプログラムにバグがあったので修正。

2021.12.20

　27C64に対応するためROMの1PinをVCCに接続し、基板をRev1.2としました。

2021.12.24

　安定性向上のためプルアップ抵抗を追加することにしました。回路図、基板データの検証が終わり次第公開を予定しています。また、エラー処理にバグがありましたのでこちらもテストが終わり次第公開したいと思います。

2021.12.26

　エラー処理のバグを修正。回路修正は後日。

2021.12.29

　MZ-700 MONITOR 1Z-009Aを入手し動作に支障がないことを確認しました。

2022.1.19

　GALが不安定動作の原因と思われるため、TTLで置き換えました。テスト環境では今のところ非常に安定しています。

　今まで不安定動作の要因と思われていた内部電源、外部電源、28C64の個体差、ブラウン管の磁気の影響、プルアップ抵抗等についてもTTLに置き換えたことで解消されています。

2022.1.23

　04D8H MONITOR リード インフォメーション代替処理のバグを修正。HU-BASIC V1.3、8080用テキスト・エディタ＆アセンブラのLOAD時に起こっていたエラーに対処。

2022.1.24

　SAVE時ファイルネームの後ろの空白に対処する処理をArduino側からMZ-80K側に変更。

　Arduinoの比較演算子の記述を見直し。

2022. 1.25

　0475H MONITOR ライト データ代替処理、04F8H MONITOR リード データ代替処理での8255初期化を廃止

　Arduino側での各コマンド受信時のdelay()を廃止

2022.1.26

　FDコマンドでロード可能なファイル種類コードは0x01のみとしていた制限を撤廃した

2022.1.28

　MZ-700用「FT.MZT」の動作をするFDZ、FDUコマンドを新設した。

2022.1.29

　特定環境下でLOAD、SAVEを行うとアプリケーションが固まってしまう原因のCMT代替処理RETURN時の割込み許可(EI)を削除。

　FDPコマンドで前ページに戻ると表示が乱れる場合がある症状を修正。

2022.1.30

　FDLコマンド仕様変更 FDL A～Zの場合、ファイル名先頭一文字を比較して一致したものだけを出力

2022.1.31

　FDLコマンド仕様変更 FDL nでのページ指定を廃止。FDL xでキーボードから入力可能なすべての文字で先頭一致とした。代わりにBキーで前の20件に戻れる機能を追加した。

　FDコマンド実行後アプリ動作が固まってしまう機械、アプリへの対処

2022.2.2

　DOSファイル名がアルファベット小文字でもFDL xで検索できるよう修正

2022.2.4

　ArduinoにMZ-1200対策

2022.2.9

　FDLコマンド仕様変更 FLD xの比較文字列を32文字以内とした。

2022.2.10

　ROMの相性について付記しました。

　アプリケーションのLOADコマンドの中でFDLコマンドが使える機能を実装しました。

2022.2.11

　アプリケーションのLOADコマンドの中でFDLコマンドが使える機能がMZ-700 MONITOR 1Z-009A、1Z-009B環境下では使えないバグを修正しました。

2022.2.15

　外部電源での起動に躓く場合の対処法を記載。

2022.2.26

　基板をRev1.5.2に更新。外部電源での稼働時において起動が躓く現象に対処。Rev1.5.1をRev1.5.2相当への改造方法を掲載。

2022.3.27

　基板のシルク印刷の向きを修正。

　アプリケーションからDOSファイル名を指定せずにSAVEしたときの挙動について追記。

2022.3.28

　誤字修正　誤「FDC及びFDDコマンド」 -> 正「FDR及びFDDコマンド」

2022.4.8

　Rev1.5.2基板でも機体によっては、電源ON時に起動に躓くことがあるようです。本体をリセットすることで解消できますが、気になる方はArduinoプログラム74行目の「delay(1000)」を「delay(1500)」ぐらいにしてみてください。

2022.4.24

　KiCad Libraryの定数を修正。

2022.5.31

　誤解を招く表現を修正

　修正前)DOSファイル名を指定せずに[CR]を押下してしまった場合、

　修正後)SD-CARDへのセーブ時にDOSファイル名を指定せずに[CR]を押下してしまった場合、

2022.6.29

　アプリケーションからのロード、セーブをSD対応とさせるパッチあてWindows用ツール「CMT2SD_CHECK」を公開しました。

　回路図にネットラベルを追加しました。

2022.6.30

　Z80フォルダの「FD_rom.BIN」を今回の「FD_rom.BIN」へ置き換えました。

　「CMT2SD_CHECK」によりパッチを当てたアプリケーションを使うときには新しい「FD_rom.BIN」への交換が必要です。

2022.8.4

　Arduinoを基板に直付けしている場合、Arduinoプログラムを書き込むときの注意点を書き加えました。

2022.9.11

　MicroSD Card Adapter用の端子を付加し、基板をRev1.5.3に更新。

2023.6.19

　MZ-2000_SDの起動方式追加によりArduinoプログラムを修正。MZ-80K_SDには影響なし。

2023.9.20

　「I/O別冊 WICS・BASEプログラム集」に掲載されているTS-700、SuperBASE-700、WICSインタプリタ、コンパイラへの対応を追加した。

2023.9.23

　Tookatoさんから報告のあった「D28C64ACZ」を動かない個体の例が報告されているROMのリストに追加しました。

2024.1.15

　SDカードは8GB以下が望ましいことを追記。

2024.3.4

　「自作アプリケーションでMZ-80K_SDからLOADするDOSファイル名を指定したい場合」を追記。

2024.3.10

　電源が入ったままでSD-CARDを抜くと再度SD-CARDを挿入してもSD-CARDにアクセスできない問題を解消した。

2024.7.29

　Tookato様作MZ-700用ロポコVersion 1.2.2をMZ-80K_SD対応とするパッチを公開しました。

2024.7.31

　MZ-700用ロポコVersion 1.2.2をMZ-80K_SD対応とするパッチをMZ-1500_SD共用にしました。

2024.8.2

　Tookato様からご指摘により、MZ-700+MZ-80K_SDでロポコを遊ぶとき、SDから起動後にS2スイッチをSDからCMTに切り替える必要があることを追記しました。

2024.8.8

　ROM切り離しスイッチの増設方法を追加しました。

2024.9.1

　専用トレイを公開しました。

2024.10.10

　ROM切り離しスイッチを標準装備としたRev1.5.5基板及び自動切り替えとしたMZ-700_SDの記述を加えました。

2025.7.31

　MZ-80シリーズでの動作について追記。

2025.12.4

　kuran_kuranさんにArduinoプログラムのバグを発見していただきました。精査した結果、不要な処理が含まれていることが原因であったため不要な処理部分を削除しました。なお、未修正のままでも実害はありません。kuran_kuranさん、ありがとうございました。

2026.8.13

　BARYONに対応しました。

　retrogamer128さんの要望により多段ロードに対応しました。

2026.8.15

　旧基板用の記述を整理しました。ロポコがMZ-80K_SD、MZ-700_SD、MZ-1500_SDに正式対応となっていますので関連の記述を削除しました。

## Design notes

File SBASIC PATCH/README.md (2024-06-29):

# MZ-700 S-BASIC 1Z-007BをMZ-80K_SD対応にするパッチ

　S-BASIC 1Z-007BはMONITOR 1Z-009A、1Z-009Bをコールしていないため、MZ-80K_SD対応にするためにパッチを当てる必要があります。

　S-BASICの仕様を把握してはいないのですが、試行錯誤の末、一応正常にMZ-80K_SDが動いていると思われますので公開します。

　たまたま動いているだけかもしれませんのでバックアップをとってからの実行をお願いします。

#### 2023.2.24 本来80K用の回路ですのでMZ-700でRAMバンクが前に出た時にROMの出力と衝突します。このパッチをS-BASICに使用する場合はMZ-700本体にストレスがかかることを承知の上使用してください。

#### 2024.6.29 従来プロッタのCIRCLE命令をつぶしてSDアクセスルーチンを置いていましたが、未使用となっているキーワードテーブルの隙間に移動しました。これによりプロッタ関連命令もすべて使えるようになりました。

## パッチプログラムについて

　SBASIC_patch1.bin、SBASIC_patch2.binの二つをS-BASICのMZTファイルに当てます。

　MZTファイルの00A1Hから00AFHまで(実アドレス0021H～002FH)をSBASIC_patch1.binと差し替えます。

　MZTファイルの2E80Hから2FE3Hまで(実アドレス2E00H～2F63H)をSBASIC_patch2.binと差し替えます。

　~~MZTファイルの5184Hから52E7Hまで(実アドレス5104H～5267H)をSBASIC_patch2.binと差し替えます。~~

　パッチを当てたファイルを「S-BASIC SD.MZT」等パッチを当てたことが識別できるファイル名で保存してお使いください。

　~~プロッタのCIRCLE命令をつぶしています。プロッタの他の命令に影響があるか検証していませんが、プロッタ関連の命令は使えないとしてください。~~

## ファイル名について

　オリジナル通りに16文字までがファイル名となりますが、半角カナ文字はArduinoが認識できない、一部の記号はMZ-700のキーボードから入力できないので使えません。

　ロングファイルネームに対応できなかった引き換えにLOADコマンドもオリジナル通りの入力方法となり、そのままDOSファイル名となります。

例)

　SAVE "TEST.BAS" : TEST.BAS.MZTというDOSファイル名で保存されます。

　SAVE "TEST"     : TEST.MZTというDOSファイル名で保存されます。

　LOAD "TEST.BAS" : TEST.BAS.MZTというDOSファイル名のファイルがロードされます。

　LOAD "TEST"     : TEST.MZTというDOSファイル名のファイルがロードされます。

　DOSファイル名が「TEST SBASIC EIGHT.MZT」の場合、LOAD "TEST SBASIC EIGHT"と入力しても「TEST SBASIC EIGH.MZT」というDOSファイルを探しに行くためロードできません。

## 使用方法
　パッチを当てたS-BASIC.MZTをFDコマンドでロードします。MONITOR 1Z-009A、1Z-009Bにパッチを当てる必要はありませんので、FT.MZTの実行も不要です。

## 追記
2021.12.26

　エラー処理のバグを修正。

2024.6.29

　SDアクセスルーチンをキーワードテーブル隙間の未使用領域に移動。

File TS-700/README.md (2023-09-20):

# MZ-700 TS-700をMZ-80K_SD対応にするパッチ

　「I/O別冊 WICS・BASEプログラム集」に掲載されているTS-700はMONITOR 1Z-009A、1Z-009Bをコールしていないため、MZ-80K_SD対応にするためにパッチを当てる必要があります。

　TS-700をMZ-80K_SD対応とすることで同誌に掲載されているSuperBASE-700、WICSインタプリタ・コンパイラもMZ-80K_SD対応となります。

　MZ-80K_SDは、本来80K用の回路ですのでMZ-700でRAMバンクが前に出た時にROMの出力と衝突します。このパッチをTS-700に使用する場合はMZ-700本体にストレスがかかることを承知の上使用してください。

## パッチプログラムについて

　APP_TS-700.bin(1465Byte)をTS-700.bin又はTS-700.mztの直後に連結して保存します。

　TS-700.binは5632Byteで連結すると7097Byteになります。

　TS-700.mztなら128Byteのヘッダが付いていますので5760Byteで連結すると7225Byteになります

　TS-700.binならヘッダをつけてMZTファイルにします。

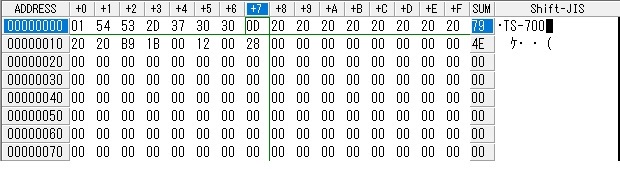
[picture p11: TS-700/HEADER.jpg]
Header


　TS-700.mztならファイルサイズと実行アドレスを修正します。

　TS-700起動時にSDアクセスルーチンは、F800h～に配置されます。BASE、WICSでプログラムを作るときにはF800h以降にオブジェクトを生成しないようにしてください。

## LOAD
　Lコマンドの後ろにはファイル名を指定せずに[CR]キーを押します。

　CMTの場合にはここでPLAYボタンを押すよう指示が出るところですが、「DOS FILE:」と表示して行入力待ちになっていますのでDOSファイル名を入力して[CR]キーを押します。この時、「.MZT」の入力は省略できます。

　DOSファイル名は「.MZT」を除いて32文字まで、ただし半角カタカナ、及び一部の記号はArduinoが認識しないので使えません。パソコンでファイル名を付けるときはアルファベット、数字および空白でファイル名をつけてください。

例)
× L TEST[CR]

○ L[CR]

　DOS FILE:TEST[CR]

### LOAD時の特殊コマンド
　「DOS FILE:」と表示して行入力待ちになったときに以下の特殊コマンドが使用可能です。

#### *FDL[CR]
#### *FDL x[CR]
　MONITORコマンド入力待ちからのFDL、FDL xと全く同等のファイル一覧機能が使えます。

　検索結果の行頭には「DOS FILE:」を付加して表示してあるのでLOADしたいファイルにカーソルキーを合わせて[CR]キーを押すだけでLOADが可能です。

　「*FDL」で検索、カーソルで選んで読み込もうとした場合に「DOS FILE:」に戻ってしまうアプリケーションがありますが、再度カーソルを合わせて[CR]すれば読み込めます。

## SAVE
　CMTの時と同様にアプリケーションの指定する入力方法、ルールでファイル名等を入力して保存してください。

　ただし、半角カタカナはArduinoが認識できないため、使用できません。アルファベット、数字および空白で指定してください。

　SAVE時は、入力したファイル名がIBFファイル名、DOSファイル名の両方に適用されます。

　DOSファイル名としての「.MZT」は自動的に付加されます。

例)

○ S8000,8FFF,8000,TEST[CR]

## BASE、WICSでのLOAD、SAVE

TS-700での扱いと同様にLOAD時にはファイル名を指定せずにDOS FILE:と聞かれたらDOSファイル名を指定します。

SAVEはBASE、WICSのSAVEの仕方と同様です。半角カタカナは使えません。入力したファイル名はIBFファイル名、DOSファイル名の両方に適用されます。

　DOSファイル名としての「.MZT」は自動的に付加されます。

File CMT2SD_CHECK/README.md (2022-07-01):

# アプリケーションからのロード、セーブをSD対応とさせるパッチあてWindows用ツール「CMT2SD_CHECK」

　MZ-80K_SDアダプタを繋ぐだけでもBASIC SP-5030が約4秒で起動できるようになるなどアプリケーションランチャーとして便利に使えますが、今まではMONITOR SP-1002にパッチをあてることを前提としていたためMONITOR ROMを交換しないとBASIC SP-5030等アプリケーションの起動はSDからできてもアプリケーションからのロード、セーブはCMTからとなってしまいます。

　そこでROMはそのままにしてアプリケーション側にSD対応パッチを当てるツールを作ってみました。

## CMT2SD_CHECKの使い方

　デスクトップ等適当な場所に「CMT2SD_CHECK.EXE」をコピーしてダブルクリックで起動させてください。

　次にSD用パッチを当てたいMZTファイルをCMT2SD_CHECKにドラッグアンドドロップしてください。

　ドロップされたアプリケーションにMONITOR SP-1002のCMT関連ルーチンを呼び出していると思われるコードが発見された場合は、元のMZTファイルと同じフォルダに元のMZTファイルのファイルネームに「_SD」を付加したMZTファイルと変更箇所を保存したTXTファイルを作成します。

　ドロップされたアプリケーションにMONITOR SP-1002のCMT関連ルーチンを呼び出していると思われるコードが無い場合には、何も作成されません。

例)

　「BASIC SP-5030.mzt」をドラッグアンドドロップ

　　BASIC SP-5030_SD.mzt、BASIC SP-5030_SD.txtが作成される。

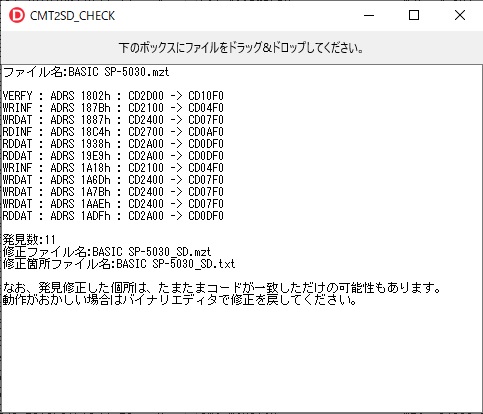
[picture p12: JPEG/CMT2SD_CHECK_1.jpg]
BASIC SP-5030


## 注意点
　「CMT2SD_CHECK.EXE」はMONITOR SP-1002のCMT関連ルーチンを呼び出していると思われるコードと一致した場合にパッチを当てますが、アプリケーションの中では命令コードではなくデータとして扱っているバイナリがたまたま一致した場合にもパッチを当ててしまいます。

　動作がおかしい場合には、変更箇所テキストファイルを参照して元に戻してください。

　また、コール命令(CD)、ジャンプ命令(C3)を使わずにCMT関連ルーチンを呼び出しているアプリケーションは検出できません。

## 「CMT2SD_CHECK.EXE」ソースコードについて
　「CMT2SD_CHECK.EXE」はDelphi 10.4Community Editionを使って作成しました。

　Pascalにしては拙いコードだとは思いますが、ご容赦願います。

## 追記
2022.6.30

　Z80フォルダの「FD_rom.BIN」を今回の「FD_rom.BIN」へ置き換えました。

　「CMT2SD_CHECK」によりパッチを当てたアプリケーションを使うときには新しい「FD_rom.BIN」への交換が必要です。

　CHECKの仕方を修正。機能に変更なし。

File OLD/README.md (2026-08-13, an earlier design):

# MZ-80シリーズにSD-Cardとのロード、セーブ機能を

MZ-80K_SD

　ROMをF000Hに置くことでMZ-80シリーズにフロッピーディスク装置を外付けした際に起動するためのFDコマンドを利用できますが、フロッピーディスク装置の代わりにSD-CARDを繋いでしまおうというものです。

#### 　2025.7.31追記 MZ-80K、MZ-80K2、MZ-80K2E、MZ-80C、MZ-1200、MZ-700で動作しますが、MZ-700はRAMとの切替動作をサポートしたMZ-700_SDもあります。

　アダプタを繋ぐだけでもBASIC SP-5030が約4秒で起動できるようになるなどアプリケーションランチャーとして便利に使えますが、MONITOR SP-1002にパッチをあてることでBASIC SP-5030はもちろん、ほとんどのMZ-80KアプリケーションがSD-CARD対応となります。

### 本体ROMをパッチを当てたMONITOR SP-1002に交換しなくてもアプリケーションからのロード、セーブをSD対応とさせるパッチあてWindows用ツール「CMT2SD_CHECK」を公開しました。(2022.6.29)
### 詳細は、CMT2SD_CHECKフォルダ中のREADME.mdを参照してください。

　MZ-700もMZ-80K用アプリケーションについては同様にSD-CARD対応となりますが、標準添付のS-BASIC、Hu-BASICともMONITOR 1Z-009A、1Z-009BのCMTルーチンを利用していないためMONITOR 1Z-009A、1Z-009BにパッチをあてただけではSD-CARD対応とならず、起動後はCMTでの運用となります。

#### (2021.12.14追記:S-BASICについてSD-CARD対応とするパッチを公開しました。)

#### (2024. 6.29追記:S-BASICについて従来プロッタのCIRCLE命令をつぶしてSDアクセスルーチンを置いていましたが、未使用となっているキーワードテーブルの隙間に移動しました。)

　基本的にはMZ-700ではMZ-80K互換機として利用できると考えてください。

　また、MZ-700もFDxコマンドは機能しますのでMZ-700用アプリケーションランチャーとして使えますが、MZ-80K対応とうたっていない64KオールRAMを前提としているMZ-700用アプリケーションはロードできない可能性があります。

　Rev1.5.5基板及びRev1.5.3基板で「ROM切り離しスイッチ改造」を行った方は、MZ-700用アプリケーション起動後はスイッチを「700」側に切り替えてください。再度SDから起動するときには「80K」に戻すのをお忘れなく。

　なお、一部のMZ-80K用ソフトはMZ-700で実行するにあたって、0h!MZ別冊 ADVANCED MZ-700に掲載されているSP-1002のMZ-700対応版 NZ-700が必要となるものがあります。

#### (2024.10.10追記:MZ-700+MZ-80K_SDでMZ-700用アプリケーションを実行したときにMZ-80K_SDのROMとMZ-700本体のRAMが衝突しないようRev1.5.5基板では「ROM切り離しスイッチ」を取り入れましたが、これを自動で行うMZ-700_SD基板も公開しています。ただし、MZ-700_SDを作成するにはGAL16V8の入手が必要です。

https://github.com/yanataka60/MZ-700_SD

#### 注）

　一応安定動作を確認していますが、SAVE動作によりSD-CARDに保存されたデータファイルの消失等考えられますのでファイルのバックアップをお願いします。

　Arduino、ROMへ書き込むための機器が別途必要となります。

### (2026.8.13追記)すねいるさんのBARYONに対応するためArduinoプログラムを更新しました。また、ROMプログラムも合わせて更新することで多段ロードにも対応します。

### 多段ロードの詳細については後述「BARYON対応」「多段ロード対応」を参照してください。

BARYON対応:https://github.com/yanataka60/MZ80K_SD#baryon%E5%AF%BE%E5%BF%9C2026813

多段ロード対応:https://github.com/yanataka60/MZ80K_SD#%E5%A4%9A%E6%AE%B5%E3%83%AD%E3%83%BC%E3%83%89%E5%AF%BE%E5%BF%9C2026813

## 回路図
　KiCadフォルダ内のMZ80K_SD.pdf参照

[回路図](https://github.com/yanataka60/MZ80K_SD/blob/main/KiCad/MZ80k_SD/MZ80K_SD.pdf)
回路図

　Rev1.5.5になりました。後述の「ROM切り離しスイッチ改造」を取り入れています。

　~~Rev1.5.3になりました。秋月電子通商　AE-microSD-LLCNVとArduino用Micro SD Card Kitのどちらかを選択して使えます。~~

　~~Rev1.5.2になりました。Rev1.5.1との違いは、外部電源での運用時にArduinoと本体の初期化のタイミングのズレにより誤動作してしまうことをArduinoのReset端子を本体のReset信号に接続し解消したことになります。~~

　~~なお、Rev1.5.1の1か所をパターンカットし、2本配線を追加することでRev1.5.2相当とする方法をKAIZOUフォルダに示しました。~~

## 部品
|番号|品名|数量|備考|
| --- | --- | --- | --- |
|U1|74LS04|1||
|U2|2764又は28C64|1|ROMの相性については後述|
|U3|8255|1||
|U4|Arduino_Pro_Mini_5V|1|Atmega328版を使用 168版は不可。(注1)|
|U5 U6|74LS30|2||
||J2、J5のいづれか|||
|J2|Micro SD Card Kit又は同等品|1|秋月電子通商 AE-microSD-LLCNV (注2) (注3)|
|J5|MicroSD Card Adapter|1|Arduino等に使われる5V電源に対応したもの (注3)|
|C1-C5|積層セラミックコンデンサ 0.1uF|5||
|C6|電解コンデンサ 16v100uF|1||
|S1 S2|3Pスライドスイッチ|2|秋月電子通商 SS12D01G4など|
|S3|3Pスライドスイッチ|1|MZ-700で使わなければ80K側固定のジャンパでも可|
|R1|カーボン抵抗 10kΩ|1|S3を使わずに80K側固定でジャンパするなら不要|
|J4|DCジャック|1||
|J3|コネクタ 2Pin|1|ピンヘッダで代用するときはGNDと間違えないよう1Pinで5Vだけにしたほうが良い|
|J1|50Pinコネクタ|1||
||50Pinケーブル|1||
||ピンヘッダ|2Pin分|Arduino_Pro_MiniにはA4、A5用のピンヘッダが付いていないため別途調達が必要です 秋月電子通商 PH-1x40SGなど|
||本体内から5Vを取る場合、ケーブル少々|||
||本体ROMにパッチをあてる場合、27C32等を2532ソケットに差すためのアダプタ|||
||ピンソケット(任意)|26Pin分|Arduino_Pro_Miniを取り外し可能としたい場合に調達します 秋月電子通商 FHU-1x42SGなど|

　　　注1)Arduino Pro MiniはA4、A5ピンも使っています。

　　　注2)秋月電子通商　AE-microSD-LLCNVのJ1ジャンパはショートしてください。

　　　注3)J2又はJ5のどちらかを選択して取り付けてください。

### MicroSD Card Adapterを使う(Rev1.5.3以降)
J5に取り付けます。

MicroSD Card Adapterについているピンヘッダを除去してハンダ付けするのが一番確実ですが、J5の穴にMicroSD Card Adapterをぴったりと押しつけ、裏から多めにハンダを流し込むことでハンダ付けをする方法もあります。なお、この方法の時にはしっかりハンダ付けが出来たかテスターで導通を確認しておいた方が安心です。

ハンダ付けに自信のない方はJ2の秋月電子通商　AE-microSD-LLCNVをお使いください。AE-microSD-LLCNVならパワーLED、アクセスLEDが付いています。

MicroSD Card Adapter1

MicroSD Card Adapter2

MicroSD Card Adapter3

MicroSD Card Adapter4

### MicroSD Card Adapterを使う(Rev1.5.2)
以下のピン番号を参考に変換基板等繋ぎ方は適宜対応してください。
|AE-microSD-LLCNVピン番号|MicroSD Card Adapterピン番号|信号名|
| --- | --- | ---- |
|1|2|5V|
|4|1|GND|
|5|5|SCK|
|6|3|MISO|
|7|4|MOSI|
|8|6|CS|

MicroSD Card Adapter

## ROMプログラムについて
　Z80フォルダ内にFD_rom1.bin、FD_rom2.bin、FD_rom.binと3つありますが、SD-CARDを利用するためのプログラムFD_rom1.bin(28C64の下位に配置)、MONITORをCMT利用に戻すためのプログラムFD_rom2.bin(28C64の上位に配置)、2つを合わせたプログラムFD_rom.binとなっています。

　ROMライター(TL866II Plus等)を使って2764又は28C64にFD_rom.binを書き込んでください。

　28C64にFD_rom.binを書き込むことでスライドスイッチによりSDとCMTを切り替えられるようにしてあります。

　ただし、稼働中に切り替えるとタイミングによってはMZ-80Kが暴走する時があります。基本的には電源を切って切り替えてください。

　また、FD_rom2の領域には4023Byte分の空きエリアがあります。自由に使っていただいて構いません。

　なお、MZ-700でMONITOR 1Z-009A、1Z-009BにMZ-80K_SD用のパッチをあてた状態でもCMT側に切り替えれば紅茶羊羹さんの「MZ⇔PC間でデータを転送する（USB版）」が問題なく使用できます。

## ROMの相性
　すべての状況をテストできたわけではないのですが、ROMの個体によっては相性があるのではないかとの報告があります。

　特に問題なく動いているROMと動かない個体の例が報告されているROMを以下に列挙します。

　これからROMを調達される方はなるべく「特に問題なく動いているROM」を調達したほうが無難だと思われます。

|特に問題なく動いているROM|
| ----------------------- |
|AT28C64B                 |
|CAT28C64BP               |
|M2764A                   |

|動かない個体の例が報告されているROM|
| --------------------------------- |
|HN484764G                          |
|M27C64A                            |
|TMM2764D                           |
|TMS2764                            |
|D28C64ACZ                          |

## Arduinoプログラム
　Arduino IDEを使ってArduinoフォルダ内のMZ-80K_SD.inoを書き込みます。

　SdFatライブラリを使用していますのでArduino IDEメニューのライブラリの管理からライブラリマネージャを立ち上げて「SdFat」をインストールしてください。

　「SdFat」で検索すれば見つかります。「SdFat」と「SdFat - Adafruit Fork」が見つかりますが「SdFat」のほうを使っています。

注)Arduinoを基板に直付けしている場合、Arduinoプログラムを書き込むときは、MZ-80K本体とは接続を外し、74LS04を外したうえで書き込んでください。

## MZ-80Kとの接続
　回路図J1のピン番号とMZ-80K外部拡張端子のピン番号は一致していません。ピン配置は一致していますのでJPGフォルダにある「Rev1.5.1+MZ-80K Series(6).JPG」を参考にフラットケーブルで接続してください。

　MZ-700の外部拡張端子はMZ-80Kとピン配置は同じですが、ピンコネクタではなく、カードエッジコネクタです。

接続1

接続2

接続3

接続4

## 電源
　MZ-80Kのバスには+5Vが出ていないため、最初はDCジャックから外部電源を供給するつもりだったのですが、本体と電源が一緒のほうが扱いが楽そうだったので本体から+5Vを引き出して供給する用のコネクタと二通りを用意しています。

　MZ-80K内部から5Vを取得するには、27C32等を2532ソケットに差すためのアダプタから引っ張ってくるのが簡単だと思います。

注)Rev1.5.1基板では、外部電源での稼働時に起動に躓くことがあるようです。内部電源での利用を推奨しますが、外部電源での稼働時にFDLコマンド等を実行しても反応が無い場合には次の手順で起動してください。

　　MZ-80K_SDの電源を入れる -> MZ-80Kの電源を入れる -> Arduinoをリセットする。

なお、Rev1.5.1基板に対して1か所をパターンカットし、2本配線を追加することでRev1.5.2基板相当とすることができます。詳しくはKAIZOUフォルダを参照してください。

　Rev1.5.2基板でも機体によっては、電源ON時に起動に躓くことがあるようです。本体をリセットすることで解消できますが、気になる方はArduinoプログラム74行目の「delay(1000)」を「delay(1500)」ぐらいにしてみてください。

## MONITOR ROMの差し替え
　MONITOR SP-1002、MONITOR 1Z-009A、1Z-009Bとも以下のパッチをあててください。

　0437 : D5 → C3

　0438 : C5 → 04

　0439 : E5 → F0

　0476 : D5 → C3

　0477 : C5 → 07

　0478 : E5 → F0

　04D9 : D5 → C3

　04DA : C5 → 0A

　04DB : E5 → F0

　04F9 : D5 → C3

　04FA : C5 → 0D

　04FB : E5 → F0

　0589 : D5 → C3

　058A : C5 → 10

　058B : E5 → F0

　MZ-700 MONITOR 1Z-009A、1Z-009Bについては、RAMにコピーしたMONITORにパッチを当てることでパッチを当てたROMに差し替えなくても済むように「FT.MZT」を作成しました。

　「FT.MZT」をSD-CARDのルートに置き、FD FT[CR]を実行することでRAM MONITORに制御が移ります。

　「FT.MZT」と同等の動作をするFDZコマンドを新設しました。FDZコマンドを使えば「FT.MZT」は必要ありません。

　また、紅茶羊羹さんの「MZ⇔PC間でデータを転送する（USB版）」でMZTrans用パッチをMONITOR 1Z-009A、1Z-009Bに当てているとFコマンドが使えないので以下のパッチを当てることで'#'コマンドをつぶして'F'コマンドを復活させます。

　00D2 : 23 → 46

　00D4 : 86 → 21

　紅茶羊羹さん作成の「TR.MZT」をSD-CARDのルートに置き、「FD TR」を実行することでMZTransを使う方法もあります。

## BASIC SP-5030 バージョン違い

　BASIC SP-5030には、旧・新・VER1.0Aの３種類のバージョンがあるそうで、そのうち新・VER1.0Aの二つはパッチをあてる必要があります。以下のアドレスが4049H、4069Hを指している場合には新・VER1.0Aのどちらかですので以下のように修正する必要があります。

アドレスはMZTファイルのアドレスです。実アドレスは()内

　18C5(1845) : 49 → 27

　18C6(1846) : 40 → 00

　1939(18B9) : 69 → 2A

　193A(18BA) : 40 → 00

　19EA(196A) : 69 → 2A

　19EB(196B) : 40 → 00

　1AE0(1A60) : 69 → 2A

　1AE1(1A60) : 40 → 00

## SD-CARD
　出来れば8GB以下のSDカードを用意してください。

　ArduinoのSdFatライブラリは、SD規格(最大2GB)、SDHC規格(2GB～32GB)に対応していますが、SDXC規格(32GB～2TB)には対応していません。

　また、SDHC規格のSDカードであっても32GB、16GBは相性により動作しないものがあるようです。

　FAT16又はFAT32が認識できます。NTFSは認識できません。

　ルートに置かれたMZTファイルのみ認識できます。(MZT以外のファイル、フォルダも表示されますがLOAD実行の対象になりません)

　ファイル名は「.MZT」を除いて32文字まで、ただし半角カタカナ、及び一部の記号はArduinoが認識しないので使えません。パソコンでファイル名を付けるときはアルファベット、数字および空白でファイル名をつけてください。

## 操作方法
　MONITORコマンド入力待ちから以下のコマンドが利用できます。

　なお、MZ-700のフロッピーディスク装置起動コマンドは本来'F'の一文字ですが、操作方法としては'FD'に統一しました。

　以下、SD-CARD内のファイルに付けられるファイル名をDOSファイル名、MZT形式ファイルのインフォメーションブロック内ファイル名をIBFファイル名とします。

### FD[CR]
　FDのみでDOSファイル名「0000.MZT」がLOAD及び実行されます。

　「0000.MZT」は、パソコンでBASIC SP-5030等をリネームコピーして作成しても大丈夫ですが、FDAコマンドから作ることもできます。

### FD　DOSファイル名[CR]
　DOSファイル名で指定したバイナリファイルをLOADして実行します。

　「.MZT」は省略可能です。

　MONITORのLOADコマンドの代替として使えます。なお、LOADコマンドも使えますが、アプリケーションからのLOADと同じ扱いになります。

例)

FD　TEST[CR]

### FD/DOSファイル名[CR] 又は FD/　DOSファイル名[CR]
　DOSファイル名で指定したバイナリファイルをLOADします。実行はしません。

　「.MZT」は省略可能です。

例)

FD/TEST[CR]

FD/　TEST[CR]

### FDL[CR]
　SD-CARDルートディレクトリにあるファイルの一覧を表示します。20件表示したところで指示待ちになるので打ち切るならSHIFT+BREAK又は↑を入力すると打ち切られ、Bキーで前の20件に戻ります。それ以外のキーで次の20件を表示します。

　行頭に「*FD」を付加して表示してあるので実行したいファイルにカーソルキーを合わせて[CR]キーを押すだけでLOAD、実行が可能です。

　表示される順番は、登録順となりファイル名アルファベッド順などのソートした順で表示することはできません。

### FDL　x[CR]
ファイル名がxで始まるファイルの一覧を表示します。20件表示したところで指示待ちになるので打ち切るならSHIFT+BREAK又は↑を入力すると打ち切られ、Bキーで前の20件に戻ります。それ以外のキーで次の20件を表示します。

xはMZのキーボードから入力可能な32文字までの文字列です。(数字、記号、アルファベット)

例)

FDL S[CR]

FDL SP[CR]

FDL BASIC S[CR]

### FDA　DOSファイル名[CR]
　DOSファイル名で指定したファイルを「0000.MZT」という名前でリネームコピーします。

　FDLコマンドで表示されたファイル名をカーソルで選択し、行頭の「*FD」に「A」だけ付加して[CR]キーを押せば簡単です。

### FDS　SAVE開始アドレス　SAVE終了アドレス　実行開始アドレス　DOSファイル名[CR]
　SAVE開始アドレスからSAVE終了アドレスまでをDOSファイル名でSAVEします。

　SAVE開始アドレス、SAVE終了アドレス、実行開始アドレスは16進数4桁で指定します。DOSファイル名の「.MZT」は省略可能です。

例)

FDS　1200　2FFF　1200　TEST[CR]

### FDC　DOSファイル名[CR]
　DOSファイル名で指定したファイルをコピーします。

　FDLコマンドで表示されたファイル名をカーソルで選択し、行頭の「*FD」に「C」だけ付加して[CR]キーを押せば簡単です。

　DOSファイル名を入力し、[CR]キーを押すと「NEW NAME:」と聞いてくるので新しいDOSファイル名を入力して[CR]キーを押します。

　新しいDOSファイル名に既にあるDOSファイル名を指定するとコピーせずに中断します。

例)

FDC　TEST[CR]

NEW NAME:TEST2[CR]

### FDR　DOSファイル名[CR]
　DOSファイル名で指定したファイルをリネームします。

　FDLコマンドで表示されたファイル名をカーソルで選択し、行頭の「*FD」に「R」だけ付加して[CR]キーを押せば簡単です。

　DOSファイル名を入力し、[CR]キーを押すと「NEW NAME:」と聞いてくるので新しいDOSファイル名を入力して[CR]キーを押します。

　新しいDOSファイル名に既にあるDOSファイル名を指定するとリネームせずに中断します。

例)

FDR　TEST[CR]

NEW NAME:TEST2[CR]

### FDD　DOSファイル名[CR]
　DOSファイル名で指定したファイルを削除します。

　FDLコマンドで表示されたファイル名をカーソルで選択し、行頭の「*FD」に「D」だけ付加して[CR]キーを押せば簡単です。

　DOSファイル名を入力し、[CR]キーを押すと「FILE DELETE?(Y:OK ELSE:CANSEL)」と聞いてくるのでYを押せば削除されます。Y以外のキーを押すとキャンセルとなります。

### FDP　DOSファイル名[CR]
　DOSファイル名で指定したファイルの内容をDUMPします。

　FDLコマンドで表示されたファイル名をカーソルで選択し、行頭の「*FD」に「P」だけ付加して[CR]キーを押せば簡単です。

　DOSファイル名を入力し、[CR]キーを押すとファイルの内容を128Byteを一画面として表示します。

　一画面表示したところで「NEXT:ANY BACK:B BREAK:SHIFT+BREAK」と表示して指示待ちとなるのでBで前の128Byteを表示、SHIFT+BREAKで中止、それ以外のキーで次の128Byteの表示となります。

　ファイルサイズが128Byteで割り切れない場合には最後のページは128Byteに揃うまで00Hで埋められます。

　ファイル内容を書き換えることはできません。

### FDM　開始アドレス[CR]
　開始アドレスからMZ-80Kのメモリ内容を128Byteを一画面として表示します。

　一画面表示したところで「NEXT:ANY BACK:B BREAK:SHIFT+BREAK」と表示して指示待ちとなるのでBで前の128Byteを表示、SHIFT+BREAKで中止、それ以外のキーで次の128Byteの表示となります。

　一画面表示している途中でもSHIFT+BREAKでいつでも中止できます。

### FDW　開始アドレス　1Byte(16進2桁)データ[CR]
　開始アドレスから16進2桁データをMZ-80Kのメモリに書き込みます。

　開始アドレスに続けて16進2桁で書き込むデータを記述し[CR]キーを押します。データの区切りの空白は無視しますのであってもなくても構いません。

　16進2桁のByteデータは一行に収まる範囲なら何Byte分を続けても構いません。

　一行入力して[CR]キーを押すとデータが書き込まれ、次のアドレスが表示されるので続けてデータを入力していけます。

　また、アドレスを修正すれば戻って修正や離れたアドレスにデータを書き込むことも可能です。

　データの書き込みを止めるときは表示されたアドレスにデータを書かずに[CR]キーを押します。

　16進数以外を入力して[CR]キーを押した場合には16進数以外を入力した直前までの有効なデータを書き込み次のアドレスを表示します。

例)

*FDW　1200　01　02　03　04　05　06　07　08[CR]

*FDW　1200　0102030405060708[CR]

*FDW　1200[CR]　(止めるとき)

*FDW　1200　12　34　5/[CR]　(12　34まで書き込まれます)

### FDZ[CR]
　【MZ-700専用】MZ-700用に作成した「FT.MZT」と同等の動きをします。 MONITOR 1Z-009A又は1Z-009Bを裏RAMにコピーしたうえでパッチを当てた後、裏RAM上のMONITORがスタートします。

　MZ-80Kで実行してしまった場合には、RESET動作となります。

### FDU[CR]
　【MZ-700専用、裏RAM MONITORで運用中にRESETした場合に限る】裏RAMに切り替え裏RAMのMONITORをスタートさせます。

　注）裏RAMにMONITORが無い状態で実行すると暴走します。

　MZ-80Kで実行してしまった場合には、RESET動作となります。

### アプリケーションからのLOAD
　L、LOAD等アプリケーションが指定したコマンドの後ろにはIBFファイル名を指定可となっていますが、指定せずにL、LOAD等のコマンドのみで[CR]キーを押します。

　CMTの場合にはここでPLAYボタンを押すよう指示が出るところですが、「DOS FILE:」と表示して行入力待ちになっていますのでDOSファイル名を入力して[CR]キーを押します。この時、「.MZT」の入力は省略できます。

　DOSファイル名は「.MZT」を除いて32文字まで、ただし半角カタカナ、及び一部の記号はArduinoが認識しないので使えません。パソコンでファイル名を付けるときはアルファベット、数字および空白でファイル名をつけてください。

例)BASIC SP-5030では

× LOAD "TEST"[CR]

○ LOAD[CR]

　DOS FILE:TEST[CR]

○ LOAD[CR]

　DOS FILE:TEST.MZT[CR]

** 参考 **

　S-OS SWORDでの運用に当たっては起動直後に「DV S:」としてデバイスを各SYSTEMデバイスとしてください。

　FUZZY BASICだけかもしれませんが共通フォーマットデバイスのままだとLOADコマンドでIBFファイル名の省略ができませんでした。

#### LOAD時の特殊コマンド
　「DOS FILE:」と表示して行入力待ちになったときに以下の特殊コマンドが使用可能です。

##### *FDL[CR]
##### *FDL x[CR]
　MONITORコマンド入力待ちからのFDL、FDL xと全く同等のファイル一覧機能が使えます。

　検索結果の行頭には「DOS FILE:」を付加して表示してあるのでLOADしたいファイルにカーソルキーを合わせて[CR]キーを押すだけでLOADが可能です。

　「*FDL」で検索、カーソルで選んで読み込もうとした場合に「DOS FILE:」に戻ってしまうアプリケーションがありますが、再度カーソルを合わせて[CR]すれば読み込めます。

### アプリケーションからのSAVE
　CMTの時と同様にアプリケーションの指定する入力方法、ルールでファイル名等を入力して保存してください。

　ただし、半角カタカナはArduinoが認識できないため、使用できません。アルファベット、数字および空白で指定してください。

　SAVE時は、入力したファイル名がIBFファイル名、DOSファイル名の両方に適用されます。

　DOSファイル名としての「.MZT」は自動的に付加されます。

例)BASIC SP-5030では

○ SAVE "TEST"[CR]

## 操作上の注意
　~~「SD-CARD INITIALIZE ERROR」と表示されたときは、SD-CARDをいったん抜き再挿入したうえでArduinoをリセットしてください。~~

　~~SD-CARDにアクセスしていない時に電源が入ったままで SD-CARDを抜いた後、再挿入しSD-CARDにアクセスすると「SD-CARD INITIALIZE ERROR」となる場合があります。再挿入した場合にはSD-CARDにアクセスする前にArduinoを必ずリセットしてください。~~

　~~SD-CARDの抜き差しは電源を切った状態で行うほうがより確実です。~~

　(2024.3.10) SD-CARDにアクセスしていない時に電源が入ったままでSD-CARDを抜くと再度SD-CARDを挿入してもSD-CARDにアクセスできない問題を解消しました。(Arduinoを最新版に書き換えてください)

　再度SD-CARDを挿入した後、FDL、LOAD、SAVE等でSD-CARDに3回ほどアクセスすれば復旧します。

　SD-CARDへのセーブ時にDOSファイル名を指定せずに[CR]を押下してしまった場合、「.MZT」というDOSファイルが作成されてしまいます。この「.MZT」はアプリケーションからLOADする時にDOSファイル名を指定せずに[CR]を押下した場合に読み込まれることで不測の動作を起こす原因になりますので作成された場合には削除しておく方が無難です。

　なお、「.MZT」は現在FDR及びFDDコマンドでは認識できませんので、Windowsパソコンから消去してください。

## SD-CARDに読み書きできるかを試した結果

　読み書き出来たもの(アルファベット順)

　　BASE-80 Ver35【I/O 1981年4月号】

　　BASIC SP-5030(パッチあて必要なバージョンあり)

　　CAP-Xインタプリタ【I/O 1980年5月号】

　　EDASM V1.2B【Oh!MZ 1985年1月号】

　　FORM VER1.0(注3)【I/O 1980年6月号】

　　FORTRAN-MZ V.1【I/O 1981年1月号】

　　GAME-MZ80K V.1(注1)【ASCII 1979年10月号】

　　HU-BASIC V1.3

　　KM-BASIC ver 0.8.3-beta(注2)

　　LSIアセンブラ(注1)【【ASCII 1979年11月号】

　　M-FORTH/MZ V1.1(注1)【I/O 1981年3月号】

　　micro PASCAL-MZ VER 2.2【ASCII 1980年6月号】

　　MONIOS【月刊マイコン 1982年2月号】

　　PALL【I/O 1979年12月号】

　　S-OS SWORD(S-OS用アプリ含む)【Oh!MZ 1986年2月号】【再掲載 Oh!MZ 1987年3月号】

　　SELF RELOCATABLE DEBUGGER【I/O 1980年11月号】

　　SP-2101 Z80 ASSEMBLER

　　SP-2201 TEXT EDITOR

　　SP-2301 RELOCATE LOADER

　　SP-2401 SYMB DEBUGGER

　　TL/1(注1)(注3)【ASCII 1981年5月号】

　　TTL VERSION 1.1【Oh!MZ 1984年10月号】

　　WICS INTERPRETER VER 1.1(注3)【I/O 1981年10月号】

　　8080用テキスト・エディタ＆アセンブラ【I/O 1980年9月号】

　　マシン語モニタ【I/O 1979年10月号】【I/O合本 MZ-80活用研究】

　　整数型ベーシックコンパイラー for MZ-80K/C, MZ-1200(注1)(注3)【諏訪工房】

注1)このアプリケーションはMZ-700非対応です。MZ-700で動かすには、0h!MZ別冊 ADVANCED MZ-700に掲載されているSP-1002のMZ-700対応版 NZ-700が必要です。NZ-700にSP-1002と同じようにMZ-80K_SDのパッチをあてることでMZ-700でも同様にLOAD、SAVEが可能となります。

注2)SAVEコマンドでファイルネームは指定できないようです。SAVE[CR]で「KMB-FILE VER 1.0」のファイルネームで保存されました。

注3)LOADコマンドから「*FDL」で検索、カーソルで選んで読み込もうとした場合に「DOS FILE:」に戻ってしまいますが、再度カーソルを合わせて[CR]すれば読み込めます。

　読み書き出来なかったもの

　　EDAS FOR MZ-1200 VER 1.2【I/O 1982年11月号】

　　EXIT MONITOR【ASCII 1981年6月号】

## MZ700用プログラムで起動確認したもの
　　S-BASIC 1Z-007B(LOAD、SAVEもSD対応となるパッチを公開しました)

　　S-OS SWORD(MZ-700用SWORDでSD-CARD運用するにはMONITOR-ROMの書き換えが必要です。MONITOR-ROMを書き換えずに「FT.MZT」又はFDZコマンドを実行しても起動後のLOAD、SAVEはCMTとなります)

　　HUBASIC VERSION 2.0A(起動後のLOAD、SAVEはCMT)

　　tiny XEVIOUS mz-700

　　タイムシークレット(すべてのプログラムを別ファイルとして保存が必要)

　　タイムトンネル(すべてのプログラムを別ファイルとして保存が必要)

　　TS-700(「I/O別冊 WICS・BASEプログラム集」掲載、TS-700フォルダ参照)

　　SuperBASE-700(「I/O別冊 WICS・BASEプログラム集」掲載、TS-700フォルダ参照)

　　WICSインタプリタ、コンパイラ(「I/O別冊 WICS・BASEプログラム集」掲載、TS-700フォルダ参照)

なお、起動確認していないアプリケーションでも起動だけであればFDコマンドで起動できる可能性があります。

## 自作アプリケーションでMZ-80K_SDからLOADするDOSファイル名を指定したい場合
　MZ-80K用自作アプリケーションでMZ-80K_SDからデータ・機械語プログラム等のバイナリデータをLOADする処理を追加したい場合にはF00Ah(MLHED)をコールしてDOSファイル名を入力した後、F00Dh(MLDAT)をコールしてデータをロードとなり、DOSファイル名をアプリケーションの中で指定しておくことが出来ません。

　そこで以下の機械語をアプリケーションに組み込み、コールすることでアプリケーション内でDOSファイル名を指定することが可能です。

　その後、F00DHをコールすればSDからLOADが実行されます。

|コード|
| ------------ |
|MLHED:　　LD　　　DE,FNAME|
|　　　　　DI|
|　　　　　PUSH　　DE|
|　　　　　PUSH　　BC|
|　　　　　PUSH　　HL|
|　　　　　CALL　　F082H|
|　　　　　PUSH　　DE|
|　　　　　XOR　　　A|
|　　　　　LD　　　DE,0000H|
|　　　　　CALL　　0033H|
|　　　　　POP　　　DE|
|　　　　　JP　　　F85BH|
|FNAME:|
|　　　　　DB　　　'TEST',0DH|

#### BASIC SP-5030のプログラム中でMZ-80K_SDからLOADするDOSファイル名を指定したい場合
　BASIC SP-5030で使うときは以下の機械語を適当なアドレスに配置し、BASICから呼び出します。

　わずかな機械語ですのでBASICプログラム中にDATA文にしておき、LIMIT文で機械語領域を確保、READ文で読み込み、POKE文でメモリに書き込むようにすれば手軽です。

|コード|
| ------------ |
|MLHED:　　DI|
|　　　　　PUSH　　DE|
|　　　　　PUSH　　BC|
|　　　　　PUSH　　HL|
|　　　　　CALL　　F082H|
|　　　　　PUSH　　DE|
|　　　　　XOR　　　A|
|　　　　　LD　　　DE,0000H|
|　　　　　CALL　　0033H|
|　　　　　POP　　　DE|
|　　　　　JP　　　F85BH|

DATA 243,213,197,229,205,130,240,213,175,017,000,000,205,051,000,209

DATA 195,091,248

##### BASIC SP-5030からの呼び出し

|コード|備考|
| --- | --- |
|G＄="TEST"|DOSファイル名を表す文字列を文字列変数に代入|
|USR(＄C000,G＄)|機械語を配置したアドレスとDOSファイル名を表す文字列を代入した文字列変数を値としてUSR関数を実行(SP-5030の場合文字列関数に代入された文字列の最後に0Dhが入ってます)|
|USR(＄F00D)|SDからデータをLOAD|

#### MZ-700でDOSファイル名を指定したい場合
　MONITOR 1Z-009A(B)上で動くアプリケーションであればF000hからのROMにバンク切替(OUT (E3h),A)することを考慮すればMZ-80Kと同じように機械語をコールすることで指定できるようになるはずです。

　S-BASIC上でDOSファイル名を指定するにはバンク切替の他、文字列関数に代入された文字列の最後が00hで終わっていること、インフォメーションブロック(IFB)の位置もMONITOR 1Z-009A(B)とは違う等の差異を解決できる方以外はハードルが高いかもしれません。

## MZ-700版ロポコのMZ-80K_SD対応パッチ
　ロポコ for MZ-80KはMZ-80K_SDにも対応していますが、元祖MZ-700版ロポコはMZ-80K_SDに対応していません。

　この度、作者のTookato様がロポコVersion 1.2.2をリリースされましたが、このアーカイブには無圧縮版のロポコが同梱されており、パッチを当てることでMZ-80K_SD対応とすることが出来ましたので公開します。

#### 2024.7.31 MZ-1500_SDと共用にしました。MZ-700+MZ-80K_SDでの使用だけでしたらダウンロードし直す必要はありません。

### 使い方
　ロポコVersion 1.2.2を入手します。

　解凍すると「Uncompressed」フォルダにROPOKO-PR.MZT、ROPOKO-AR.MZT、ROPOKO-BR.MZT、の三つのファイルがあるのでSDカードにコピーします。

　このGitHubのMZ80K_SDリポジトリ中の「ROPOKO」フォルダ内の「ROPOKO-SD.MZT」をSDカードにコピーします。

　FDL又はFDコマンドを使ってSDカードにコピーした「ROPOKO-SD.MZT」を実行します。

　ROPOKO-PR.MZTを自動的に読込み、SD対応のパッチを当て、ロポコが起動します。

#### 2024.8.2 MZ-700+MZ-80K_SDでロポコがSDから起動できたらS2スイッチをSDからCMTに切り替えてゲームを開始してください。SDのままゲームを続けると文字化けが発生するときがあるとTookato様からご報告いただきました。

　シナリオの読込は、例えばシナリオAを選択し、「テープをセットしてください」と表示された後にCRを一回押すと「DOS FILE:」と表示されるので「ROPOKO-AR」と正しく入力し、CRを押すことで読み込みが始まります。

　データのセーブ・ロードはF3キーを押し、S:Save L:Loadを選択するとファイル名の入力になります。A面では「SA-」B面では「SB-」で始まるファイル名とし「SA-1/2/3...」のように異なる名前を付けるところはオリジナルと同様です。

　ただし、セーブ時に既にあるファイル名を指定すると上書きしますのでお気を付けください。

### ROM切り離しスイッチ改造
　MZ-80K_SDはMZ-700での使用をMZ-80K互換機としても使える程度にしか考えていなかったため、Tookato様からご報告いただいたようにMZ-700版ロポコをMZ-80K_SD対応パッチで遊んだ場合にRAMとの衝突で文字化けが発生します。

　ロポコがSDから起動できたらS2スイッチをSDからCMTに切り替えてゲームを開始すれば回避できるようですが、ゲーム開始後はいっそROMを切り離した方が安心です。

　そこで以下のようにパターンカットとスライドスイッチの増設をすればROM切り離しが出来ます。

#### Rev1.5.5では標準装備としました。

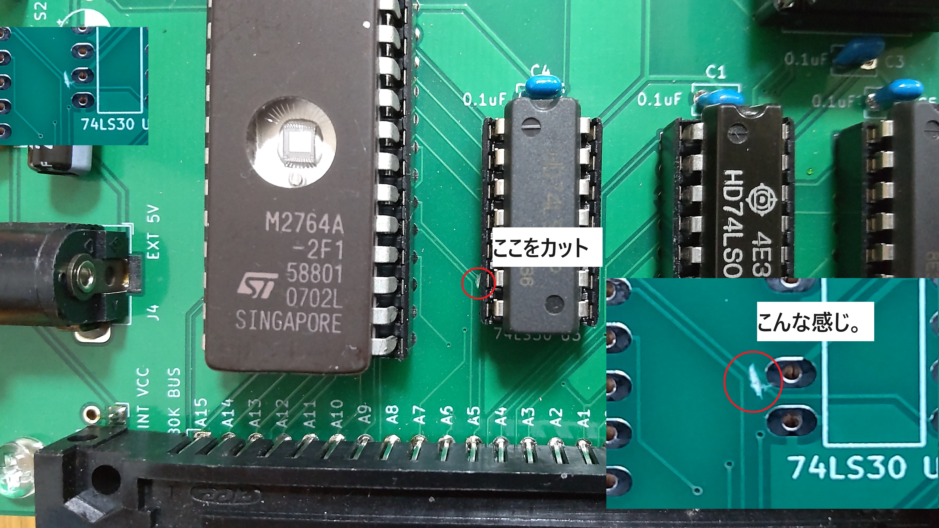
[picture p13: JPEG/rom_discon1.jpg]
rom_discon1


　U5 LS30 6Pinのすぐ左横を通るパターンをカットします。もうひとつ左を通るパターンに傷をつけないよう注意します。6Pin側にはパターンは無いので6Pinの左横をカットするくらいの気持ちで大丈夫です。

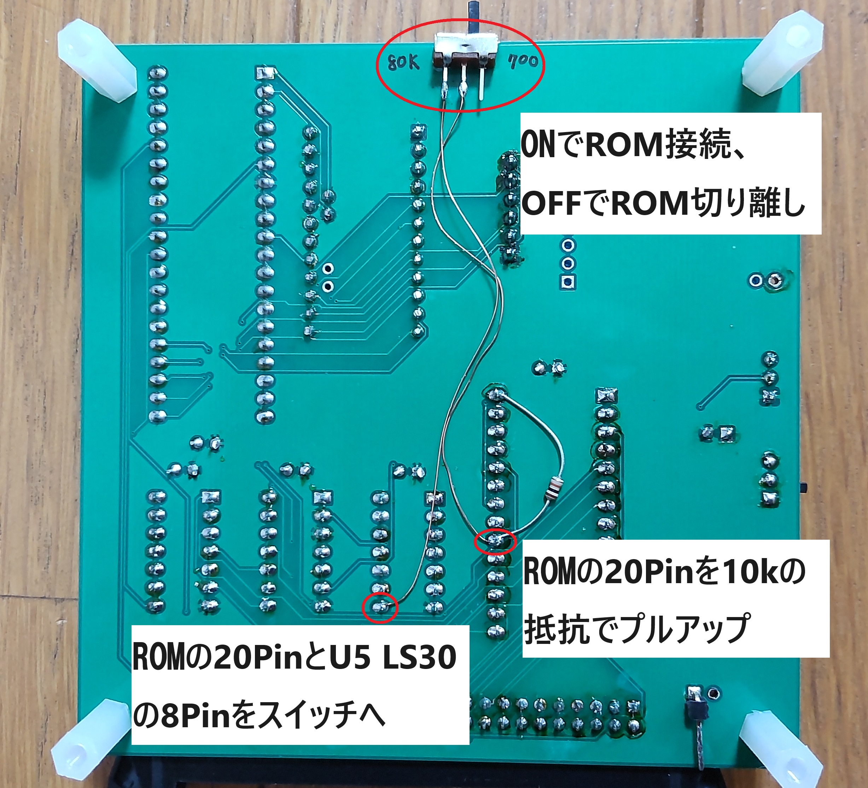
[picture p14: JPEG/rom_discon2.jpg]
rom_discon2


　10kの抵抗でROMの20Pinと28Pinを接続し、20Pinをプルアップします。

　ROMの20PinとU5 LS30の8Pinをスライドスイッチを接続します。

　スイッチONでROMが接続状態、OFFで切り離しとなります。

　スライドスイッチをまずROM接続側にしてロポコを起動します。ロポコが起動できたらスライドスイッチをROM切り離し側にしてゲームを開始してください。

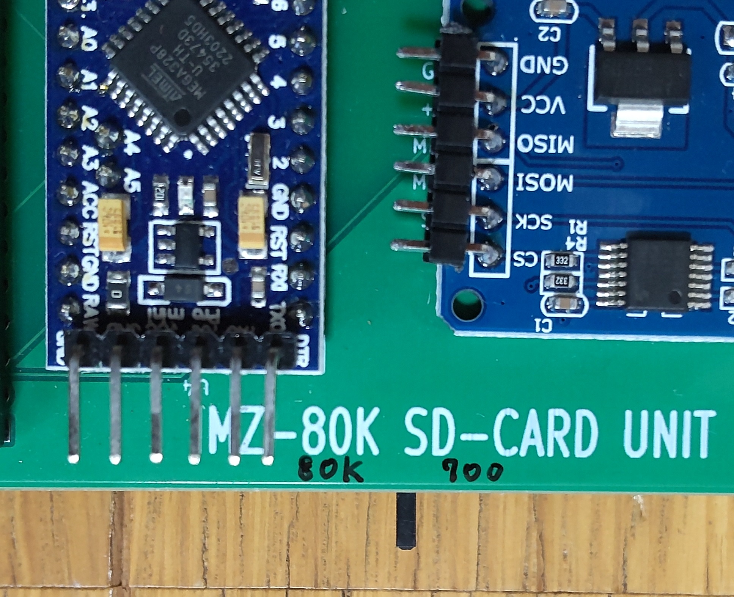
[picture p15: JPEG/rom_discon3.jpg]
rom_discon3


　部品面から見るとこんな感じです。

## ロポコ(体験版)のMZ-80K_SD対応パッチ
　MZ-700版ロポコと同様にロポコ(体験版)もパッチを作成しました。

### 使い方
　ロポコ(体験版)を入手します。

　解凍すると「Uncompressed」フォルダにROPOKO-TR.mztがあるのでSDカードにコピーします。

　このGitHubのMZ80K_SDリポジトリ中の「ROPOKO-TRIAL」フォルダ内の「ROPOKO-T-SD.MZT」をSDカードにコピーします。

　FDL又はFDコマンドを使ってSDカードにコピーした「ROPOKO-T-SD.MZT」を実行します。

　ROPOKO-TR.mztを自動的に読込み、SD対応のパッチを当て、ロポコ(体験版)が起動します。

　データのセーブ・ロードはF3キーを押し、S:Save L:Loadを選択するとファイル名の入力になります。A面では「SA-」B面では「SB-」で始まるファイル名とし「SA-1/2/3...」のように異なる名前を付けるところはオリジナルと同様です。

　ただし、セーブ時に既にあるファイル名を指定すると上書きしますのでお気を付けください。

## 専用トレイ
　カセット部に被せて使うMZ-80K_SD用トレイを公開しました。

https://yanataka.booth.pm/items/6058283

　MZ-1200用はこちらです。

https://yanataka.booth.pm/items/6069703

## BARYON対応(2026.8.13)
　MZ-700本体ROMにMZ-80K_SD(MZ-700_SD)用パッチを当てていなければBARYONの3分割mztファイル(baryon-1.mzt,baryon-2.mzt,baryon-3.mzt)で問題なく起動しますが、MZ-700本体ROMにMZ-80K_SD(MZ-700_SD)用パッチを当てていると異常動作により起動できません。

　これに対応するため、Arduinoプログラムを更新しましたので書き換えてください。

　これによりBARYON 3分割mztファイル(baryon-1.mzt,baryon-2.mzt,baryon-3.mzt)が正常に起動するようになります。

　また3つのmztファイルを連結したものとして提供されているbaryon.mztを「baryon$.mzt」とファイルネームの最後に「$」を付けることで起動できるようになりました。

## 多段ロード対応(2026.8.13)
　Arduino、ROMの両方を更新することで次の４種類の多段ロードに対応します。

### ①複数mztファイル連続読み込み
　連続して読み込ませたいmztファイルのファイル名の最後に#n(n=1～9)連続する数字を付加します。

例)

hoge#1.mzt

hoge#2.mzt

hoge#3.mzt

### ②連結mzt
　連続して読み込ませたいmztファイルを単純にマージしたmztファイルです。ファイル名の最後に#を付加してください。

例)

hoge#.mzt

### ③連続データブロック形式(IFB、DATA、DATA…)[ダミーヘッダ無]
　インフォーメションブロックに続き、複数のデータブロックが配置されたmztファイルです。実機CMTファイルで多段ロードに使用されることがある形式でダミーヘッダはありません。ファイル名に制限はありません。

例)

hoge.mzt

### ④連続データブロック形式(IFB、DATA、(IFB)、DATA…)[ダミーヘッダ有]
　インフォーメションブロックに続き、複数のデータブロックが配置されたmztファイルです。③の形式ですが、IFBがないと動作しないエミュレータ用にダミーヘッダが付加されたものです。③と区別するためにファイル名の最後に$を付加してください。

例)

hoge$.mzt

## 謝辞
　基板の作成に当たり以下のデータを使わせていただきました。ありがとうございました。

　Arduino Pro Mini

　　https://github.com/g200kg/kicad-lib-arduino

　AE-microSD-LLCNV

　　https://github.com/kuninet/PC-8001-SD-8kRAM

　MZ-700への対応に当たっては、紅茶羊羹様の「MZ⇔PC間でデータを転送する（USB版）」が非常に参考になりました。ありがとうございました。

　不安定動作の解消に以下の皆様にご協力とご助言をいただきました。ありがとうございました。(アルファベット順)

　　EIJ様

　　hlide fremen様

　　junk_suga様

　　retrogamer128様

　Arduino等に使われる5V電源に対応したMicroSD Card Adapterを使って作られた事例をご報告いただきました。ありがとうございました。

　　𝕊𝕖ñ𝕠𝕣 𝔼𝕤𝕥𝕖𝕓𝕒𝕟様

## 追記
2021.12.12

　MZ-700をMZ-80Kの代わりとして使うだけならNZ-700を最初に起動すればパッチを当てたROMを焼かなくてもいいんだと気づきました。FDコマンドでNZ-700が起動するようにすればMZ-700のほうがハードルが低いかもしれません。

2021.12.12

　MZ-700用に「FT.MZT」を作成しました。

2021.12.13

　KiCad\MZ80k_SDフォルダの回路図MZ80K_SD.pdfをRev1.1に更新

2021.12.13

　MZ-80KのS-OS SWORDでアプリケーションをLOADしようとしたとき、最初の一回だけはなぜかインフォメーションブロックの読み込みで止まってしまい、継続するためにはキーを一回押す必要がある原因は、FLGETのDEBUGにMZ-700用の修正もしてしまっていたせいでした。元に戻したところ無事解消。

2021.12.14

　S-BASICについてSD-CARD対応とするパッチを公開しました。

2021.12.18 2021.12.19 2021.12.21

　(MZ-80Kの電源状況によっては内部電源では動作不安定になることもあるようです。不安定な挙動がある場合には外部電源を試してください。)

　昨日追記した挙動不安定は電源のせいではなく、28C64がハズレあるいは個体差によりブラウン管の磁気の影響を受けていたためでした。

　28C64に個体差があるとは思われますが、それを吸収すべきプログラムにバグがあったので修正。

2021.12.20

　27C64に対応するためROMの1PinをVCCに接続し、基板をRev1.2としました。

2021.12.24

　安定性向上のためプルアップ抵抗を追加することにしました。回路図、基板データの検証が終わり次第公開を予定しています。また、エラー処理にバグがありましたのでこちらもテストが終わり次第公開したいと思います。

2021.12.26

　エラー処理のバグを修正。回路修正は後日。

2021.12.29

　MZ-700 MONITOR 1Z-009Aを入手し動作に支障がないことを確認しました。

2022.1.19

　GALが不安定動作の原因と思われるため、TTLで置き換えました。テスト環境では今のところ非常に安定しています。

　今まで不安定動作の要因と思われていた内部電源、外部電源、28C64の個体差、ブラウン管の磁気の影響、プルアップ抵抗等についてもTTLに置き換えたことで解消されています。

2022.1.23

　04D8H MONITOR リード インフォメーション代替処理のバグを修正。HU-BASIC V1.3、8080用テキスト・エディタ＆アセンブラのLOAD時に起こっていたエラーに対処。

2022.1.24

　SAVE時ファイルネームの後ろの空白に対処する処理をArduino側からMZ-80K側に変更。

　Arduinoの比較演算子の記述を見直し。

2022. 1.25

　0475H MONITOR ライト データ代替処理、04F8H MONITOR リード データ代替処理での8255初期化を廃止

　Arduino側での各コマンド受信時のdelay()を廃止

2022.1.26

　FDコマンドでロード可能なファイル種類コードは0x01のみとしていた制限を撤廃した

2022.1.28

　MZ-700用「FT.MZT」の動作をするFDZ、FDUコマンドを新設した。

2022.1.29

　特定環境下でLOAD、SAVEを行うとアプリケーションが固まってしまう原因のCMT代替処理RETURN時の割込み許可(EI)を削除。

　FDPコマンドで前ページに戻ると表示が乱れる場合がある症状を修正。

2022.1.30

　FDLコマンド仕様変更 FDL A～Zの場合、ファイル名先頭一文字を比較して一致したものだけを出力

2022.1.31

　FDLコマンド仕様変更 FDL nでのページ指定を廃止。FDL xでキーボードから入力可能なすべての文字で先頭一致とした。代わりにBキーで前の20件に戻れる機能を追加した。

　FDコマンド実行後アプリ動作が固まってしまう機械、アプリへの対処

2022.2.2

　DOSファイル名がアルファベット小文字でもFDL xで検索できるよう修正

2022.2.4

　ArduinoにMZ-1200対策

2022.2.9

　FDLコマンド仕様変更 FLD xの比較文字列を32文字以内とした。

2022.2.10

　ROMの相性について付記しました。

　アプリケーションのLOADコマンドの中でFDLコマンドが使える機能を実装しました。

2022.2.11

　アプリケーションのLOADコマンドの中でFDLコマンドが使える機能がMZ-700 MONITOR 1Z-009A、1Z-009B環境下では使えないバグを修正しました。

2022.2.15

　外部電源での起動に躓く場合の対処法を記載。

2022.2.26

　基板をRev1.5.2に更新。外部電源での稼働時において起動が躓く現象に対処。Rev1.5.1をRev1.5.2相当への改造方法を掲載。

2022.3.27

　基板のシルク印刷の向きを修正。

　アプリケーションからDOSファイル名を指定せずにSAVEしたときの挙動について追記。

2022.3.28

　誤字修正　誤「FDC及びFDDコマンド」 -> 正「FDR及びFDDコマンド」

2022.4.8

　Rev1.5.2基板でも機体によっては、電源ON時に起動に躓くことがあるようです。本体をリセットすることで解消できますが、気になる方はArduinoプログラム74行目の「delay(1000)」を「delay(1500)」ぐらいにしてみてください。

2022.4.24

　KiCad Libraryの定数を修正。

2022.5.31

　誤解を招く表現を修正

　修正前)DOSファイル名を指定せずに[CR]を押下してしまった場合、

　修正後)SD-CARDへのセーブ時にDOSファイル名を指定せずに[CR]を押下してしまった場合、

2022.6.29

　アプリケーションからのロード、セーブをSD対応とさせるパッチあてWindows用ツール「CMT2SD_CHECK」を公開しました。

　回路図にネットラベルを追加しました。

2022.6.30

　Z80フォルダの「FD_rom.BIN」を今回の「FD_rom.BIN」へ置き換えました。

　「CMT2SD_CHECK」によりパッチを当てたアプリケーションを使うときには新しい「FD_rom.BIN」への交換が必要です。

2022.8.4

　Arduinoを基板に直付けしている場合、Arduinoプログラムを書き込むときの注意点を書き加えました。

2022.9.11

　MicroSD Card Adapter用の端子を付加し、基板をRev1.5.3に更新。

2023.6.19

　MZ-2000_SDの起動方式追加によりArduinoプログラムを修正。MZ-80K_SDには影響なし。

2023.9.20

　「I/O別冊 WICS・BASEプログラム集」に掲載されているTS-700、SuperBASE-700、WICSインタプリタ、コンパイラへの対応を追加した。

2023.9.23

　Tookatoさんから報告のあった「D28C64ACZ」を動かない個体の例が報告されているROMのリストに追加しました。

2024.1.15

　SDカードは8GB以下が望ましいことを追記。

2024.3.4

　「自作アプリケーションでMZ-80K_SDからLOADするDOSファイル名を指定したい場合」を追記。

2024.3.10

　電源が入ったままでSD-CARDを抜くと再度SD-CARDを挿入してもSD-CARDにアクセスできない問題を解消した。

2024.7.29

　Tookato様作MZ-700用ロポコVersion 1.2.2をMZ-80K_SD対応とするパッチを公開しました。

2024.7.31

　MZ-700用ロポコVersion 1.2.2をMZ-80K_SD対応とするパッチをMZ-1500_SD共用にしました。

2024.8.2

　Tookato様からご指摘により、MZ-700+MZ-80K_SDでロポコを遊ぶとき、SDから起動後にS2スイッチをSDからCMTに切り替える必要があることを追記しました。

2024.8.8

　ROM切り離しスイッチの増設方法を追加しました。

2024.9.1

　専用トレイを公開しました。

2024.10.10

　ROM切り離しスイッチを標準装備としたRev1.5.5基板及び自動切り替えとしたMZ-700_SDの記述を加えました。

2025.7.31

　MZ-80シリーズでの動作について追記。

2025.12.4

　kuran_kuranさんにArduinoプログラムのバグを発見していただきました。精査した結果、不要な処理が含まれていることが原因であったため不要な処理部分を削除しました。なお、未修正のままでも実害はありません。kuran_kuranさん、ありがとうございました。

2026.8.13

　BARYONに対応しました。

　retrogamer128さんの要望により多段ロードに対応しました。

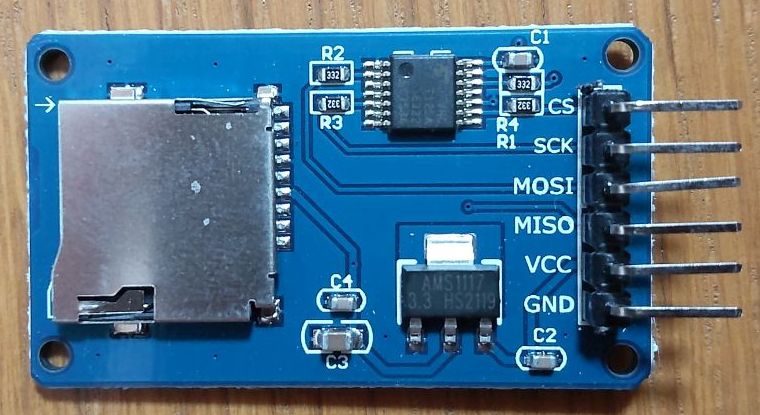
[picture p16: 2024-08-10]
JPEG/MicroSD Card Adapter.JPG

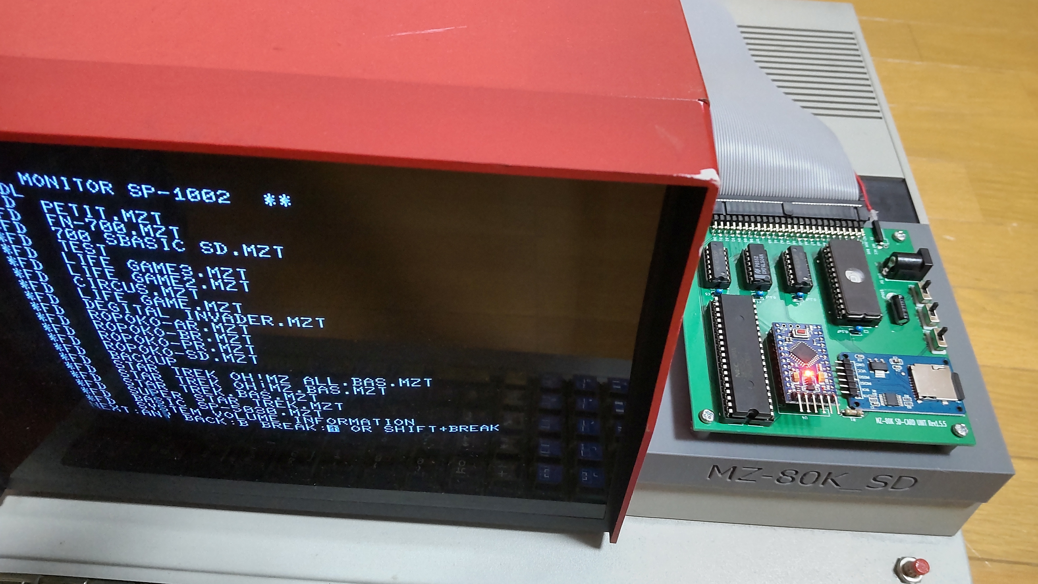
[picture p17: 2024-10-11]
JPEG/Rev1.5.5+MZ-80K Series(2).JPG

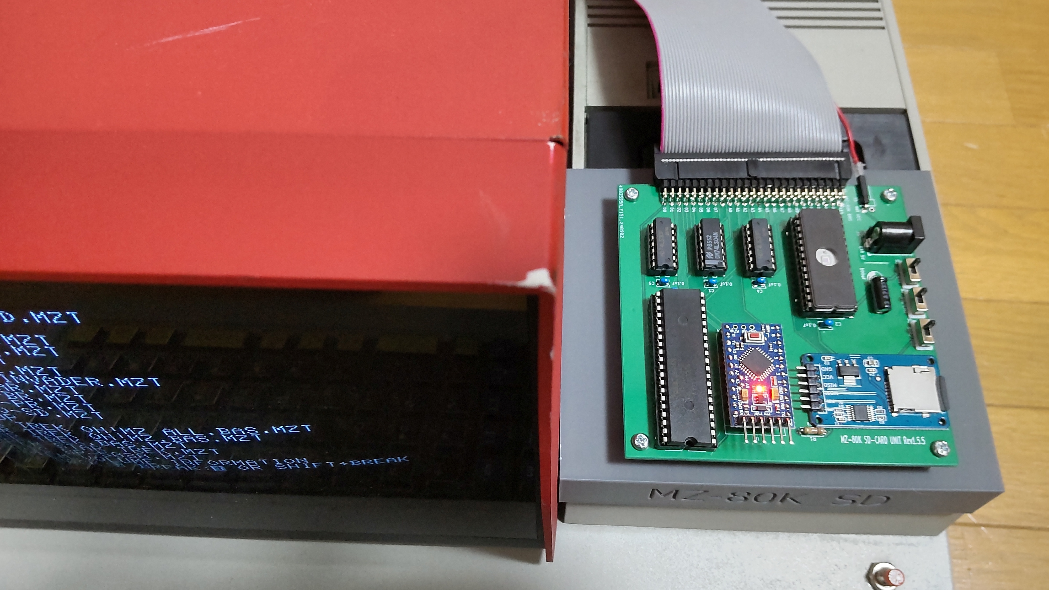
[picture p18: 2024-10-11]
JPEG/Rev1.5.5+MZ-80K Series(3).JPG

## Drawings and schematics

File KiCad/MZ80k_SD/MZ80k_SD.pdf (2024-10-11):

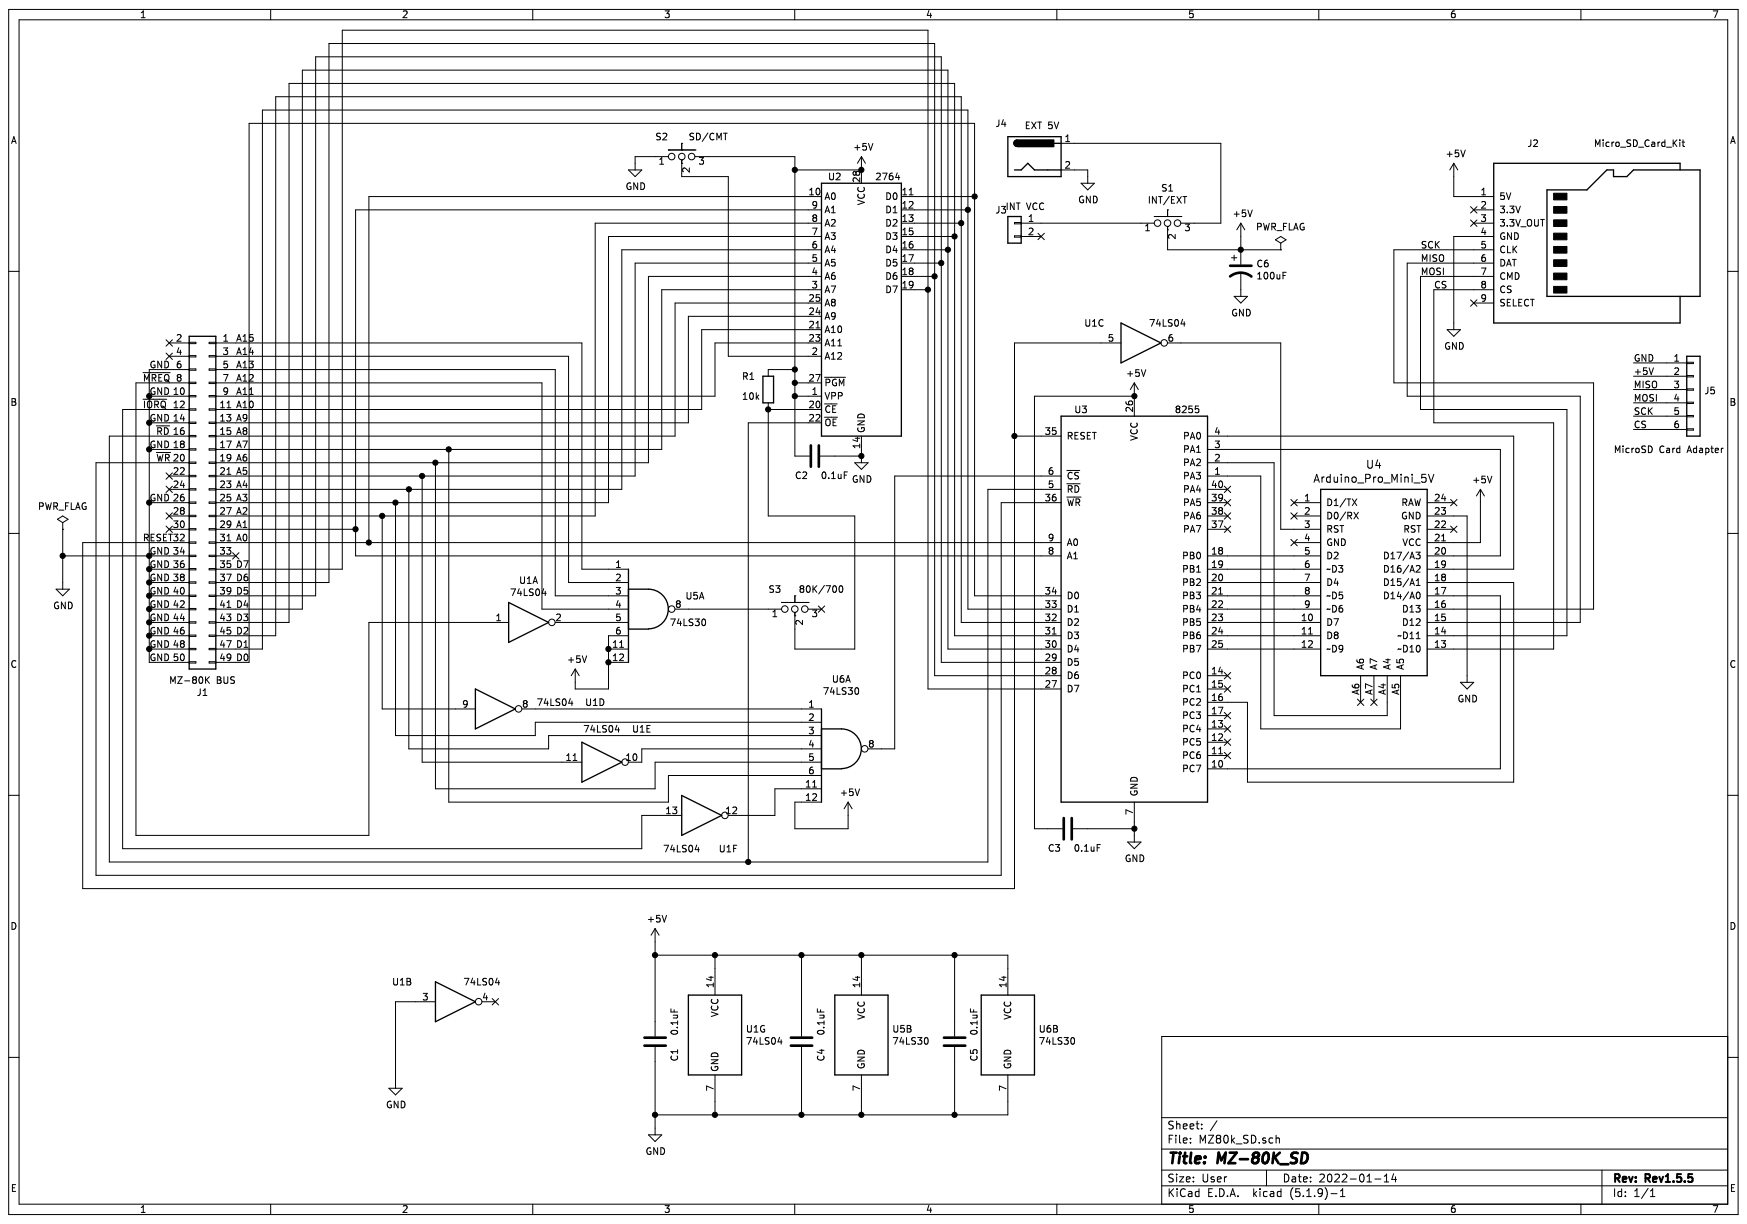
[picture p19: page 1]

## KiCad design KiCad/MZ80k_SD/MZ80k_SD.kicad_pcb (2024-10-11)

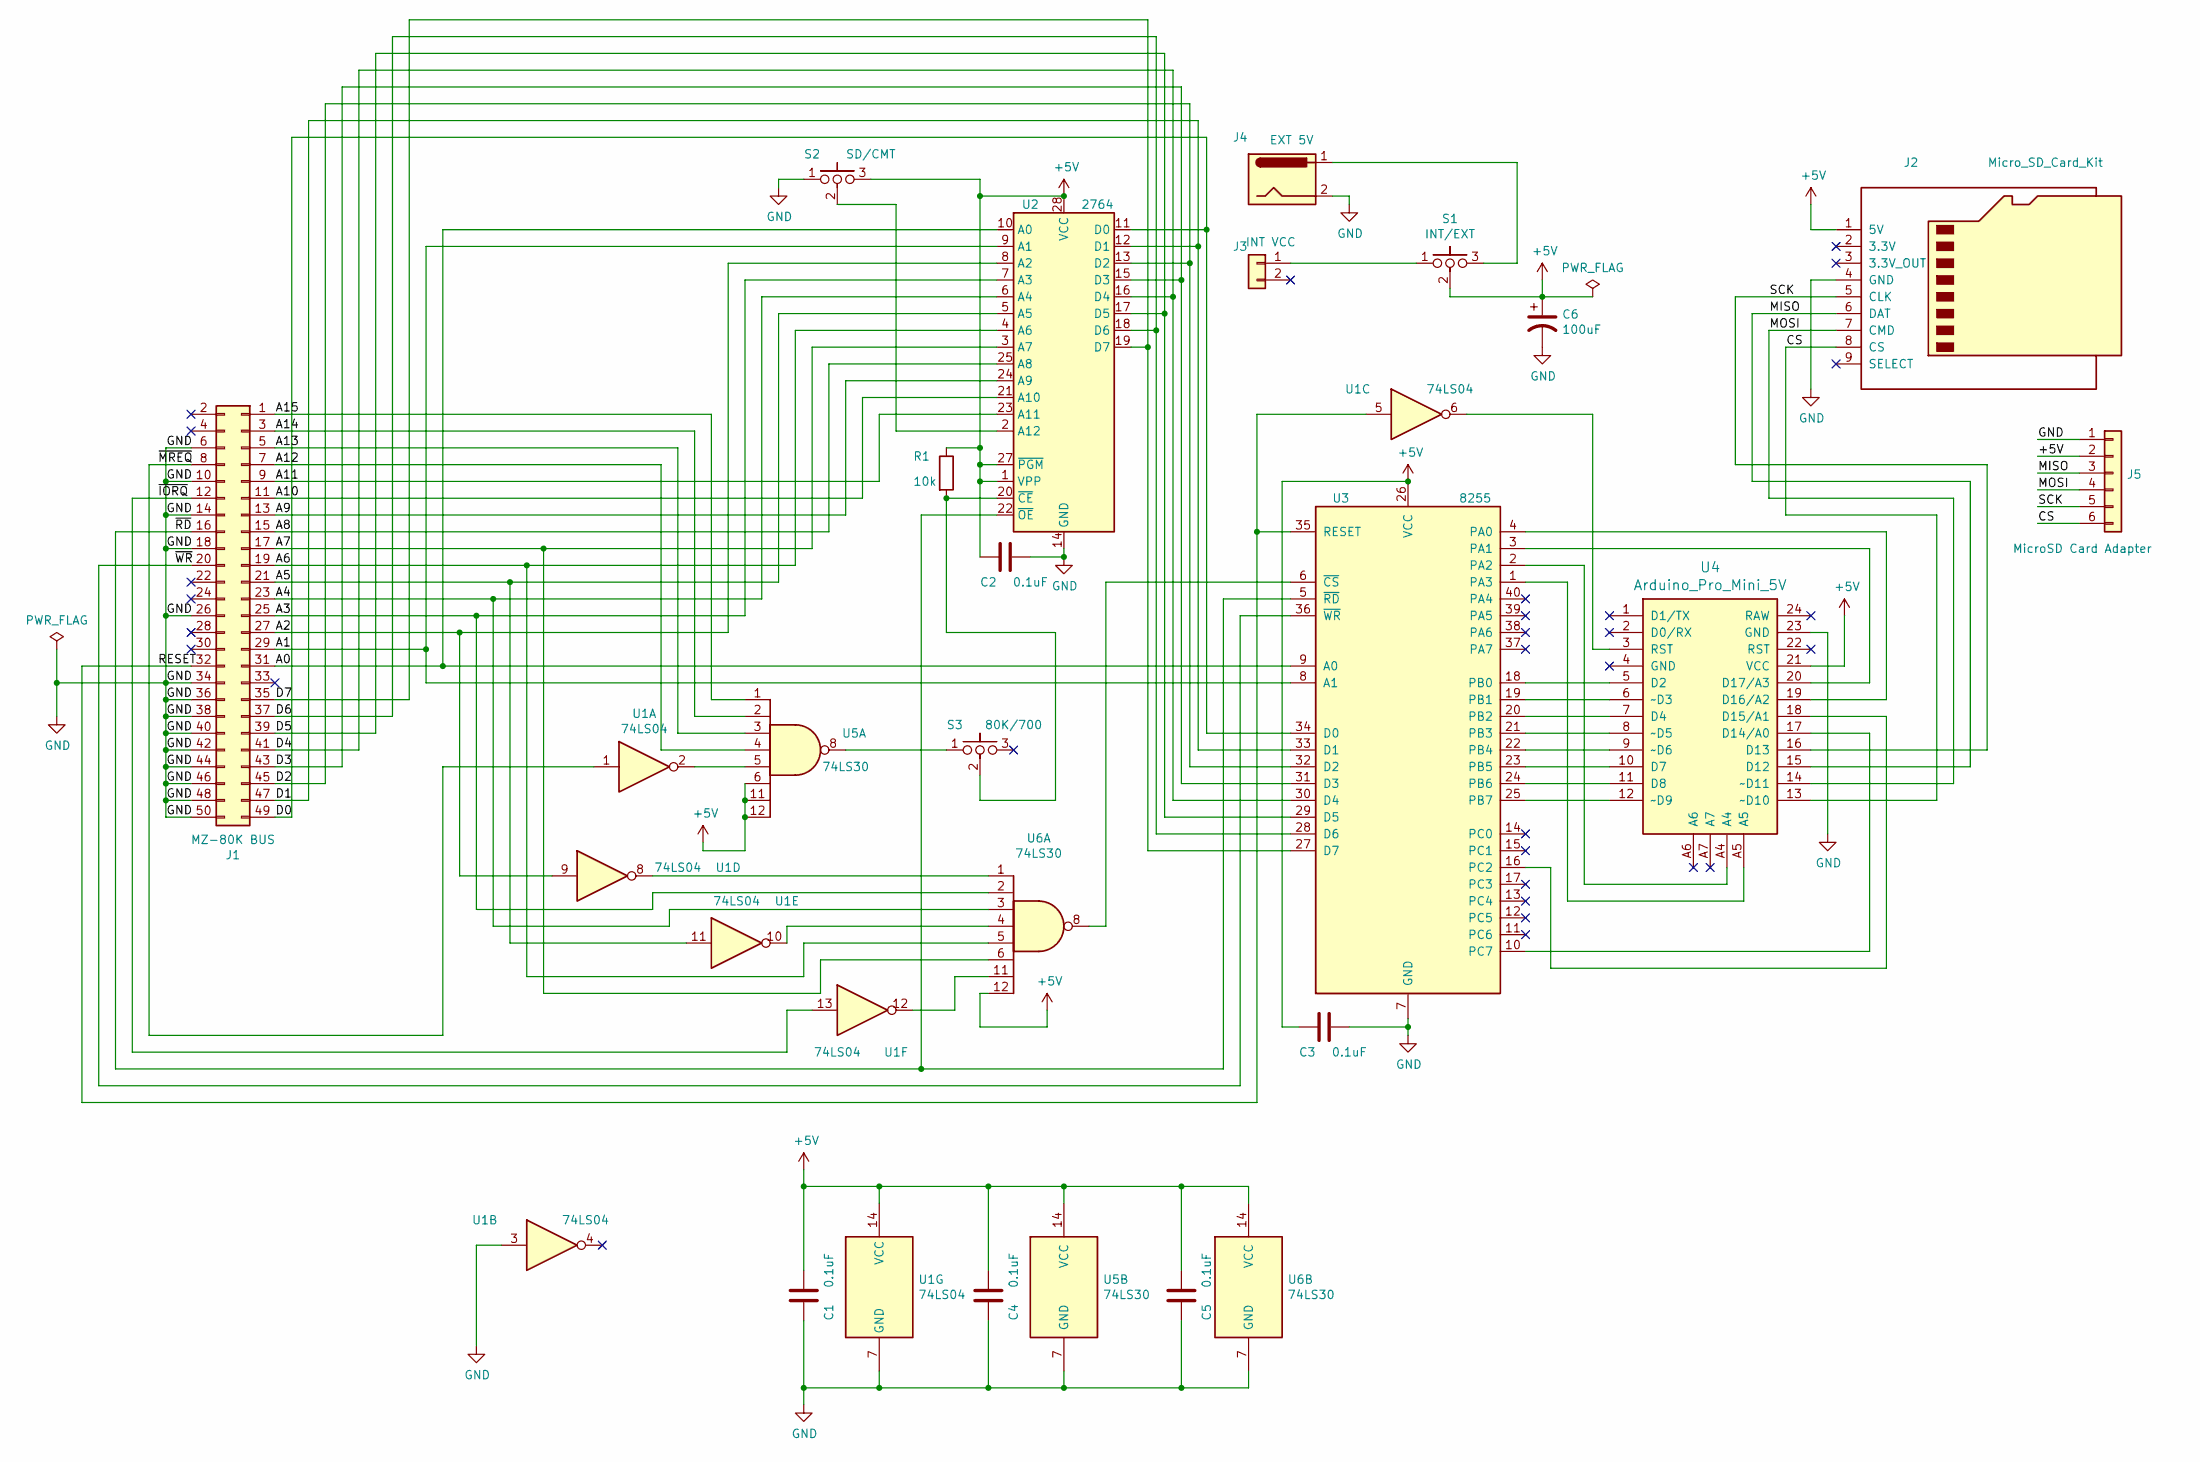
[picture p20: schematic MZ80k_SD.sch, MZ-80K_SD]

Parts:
C1, C2, C3, C4, C5: 0.1uF; C_Rect_L4.0mm_W2.5mm_P2.50mm
C6: 100uF; CP_Radial_D5.0mm_P2.50mm
J1: MZ-80K BUS; PinSocket_2x25_P2.54mm_Horizontal
J2: Micro_SD_Card_Kit; AE-microSD-LLCNV
J3: INT VCC; PinHeader_1x02_P2.54mm_Horizontal
J4: EXT 5V; BarrelJack_Horizontal
J5: MicroSD Card Adapter; PinSocket_1x06_P2.54mm_Vertical
R1: 10k; R_Axial_DIN0207_L6.3mm_D2.5mm_P7.62mm_Horizontal
S1: INT/EXT; PinHeader_1x03_P2.54mm_Vertical
S2: SD/CMT; PinHeader_1x03_P2.54mm_Vertical
S3: 80K/700; PinHeader_1x03_P2.54mm_Vertical
U1: 74LS04; DIP-14_W7.62mm_LongPads
U2: 2764; DIP-28_W15.24mm_LongPads
U3: 8255; DIP-40_W15.24mm_LongPads
U4: Arduino_Pro_Mini_5V; Arduino_Pro_Mini
U5, U6: 74LS30; DIP-14_W7.62mm_LongPads

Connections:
+5V: C1.2, C2.1, C3.1, C4.2, C5.2, C6.1, J2.1 (5V), J5.2, R1.1, S1.2, S2.3, U1.14 (VCC), U2.1 (VPP), U2.27 (~PGM), U2.28 (VCC), U3.26 (VCC), U4.21 (VCC), U5.6, U5.11, U5.12, U5.14 (VCC), U6.12, U6.14 (VCC)
/A0: J1.31, U2.10 (A0), U3.9 (A0)
/A1: J1.29, U2.9 (A1), U3.8 (A1)
/A2: J1.27, U1.9, U2.8 (A2)
/A3: J1.25, U2.7 (A3), U6.2
/A4: J1.23, U2.6 (A4), U6.3
/A5: J1.21, U1.11, U2.5 (A5)
/A6: J1.19, U2.4 (A6), U6.5
/A7: J1.17, U2.3 (A7), U6.6
/A8: J1.15, U2.25 (A8)
/A9: J1.13, U2.24 (A9)
/A10: J1.11, U2.21 (A10)
/A11: J1.9, U2.23 (A11)
/A12: J1.7, U5.4
/A13: J1.5, U5.3
/A14: J1.3, U5.2
/A15: J1.1, U5.1
/CS: J2.8 (CS), J5.6, U4.13 (~~D10)
/D0: J1.49, U2.11 (D0), U3.34 (D0)
/D1: J1.47, U2.12 (D1), U3.33 (D1)
/D2: J1.45, U2.13 (D2), U3.32 (D2)
/D3: J1.43, U2.15 (D3), U3.31 (D3)
/D4: J1.41, U2.16 (D4), U3.30 (D4)
/D5: J1.39, U2.17 (D5), U3.29 (D5)
/D6: J1.37, U2.18 (D6), U3.28 (D6)
/D7: J1.35, U2.19 (D7), U3.27 (D7)
/MISO: J2.6 (DAT), J5.3, U4.15 (D12)
/MOSI: J2.7 (CMD), J5.4, U4.14 (~~D11)
/RESET: J1.32, U1.5, U3.35 (RESET)
/SCK: J2.5 (CLK), J5.5, U4.16 (D13)
/~IORQ: J1.12, U1.13
/~MREQ: J1.8, U1.1
/~RD: J1.16, U2.22 (~OE), U3.5 (~RD~)
/~WR: J1.20, U3.36 (~WR~)
GND: C1.1, C2.2, C3.2, C4.1, C5.1, C6.2, J1.6, J1.10, J1.14, J1.18, J1.26, J1.34, J1.36, J1.38, J1.40, J1.42, J1.44, J1.46, J1.48, J1.50, J2.4 (GND), J4.2, J5.1, S2.1, U1.3, U1.7 (GND), U2.14 (GND), U3.7 (GND), U4.23 (GND), U5.7 (GND), U6.7 (GND)
unnamed: J3.1, S1.1
unnamed: J4.1, S1.3
unnamed: R1.2, S3.2, U2.20 (~CE)
unnamed: S2.2, U2.2 (A12)
unnamed: S3.1, U5.8
unnamed: U1.2, U5.5
unnamed: U1.6, U4.3 (RST)
unnamed: U1.8, U6.1
unnamed: U1.10, U6.4
unnamed: U1.12, U6.11
unnamed: U3.1 (PA3), U4.A5
unnamed: U3.2 (PA2), U4.A4
unnamed: U3.3 (PA1), U4.20 (D17/A3)
unnamed: U3.4 (PA0), U4.19 (D16/A2)
unnamed: U3.6 (~CS~), U6.8
unnamed: U3.10 (PC7), U4.17 (D14/A0)
unnamed: U3.16 (PC2), U4.18 (D15/A1)
unnamed: U3.18 (PB0), U4.5 (D2)
unnamed: U3.19 (PB1), U4.6 (~~D3)
unnamed: U3.20 (PB2), U4.7 (D4)
unnamed: U3.21 (PB3), U4.8 (~~D5)
unnamed: U3.22 (PB4), U4.9 (~~D6)
unnamed: U3.23 (PB5), U4.10 (D7)
unnamed: U3.24 (PB6), U4.11 (D8)
unnamed: U3.25 (PB7), U4.12 (~~D9)

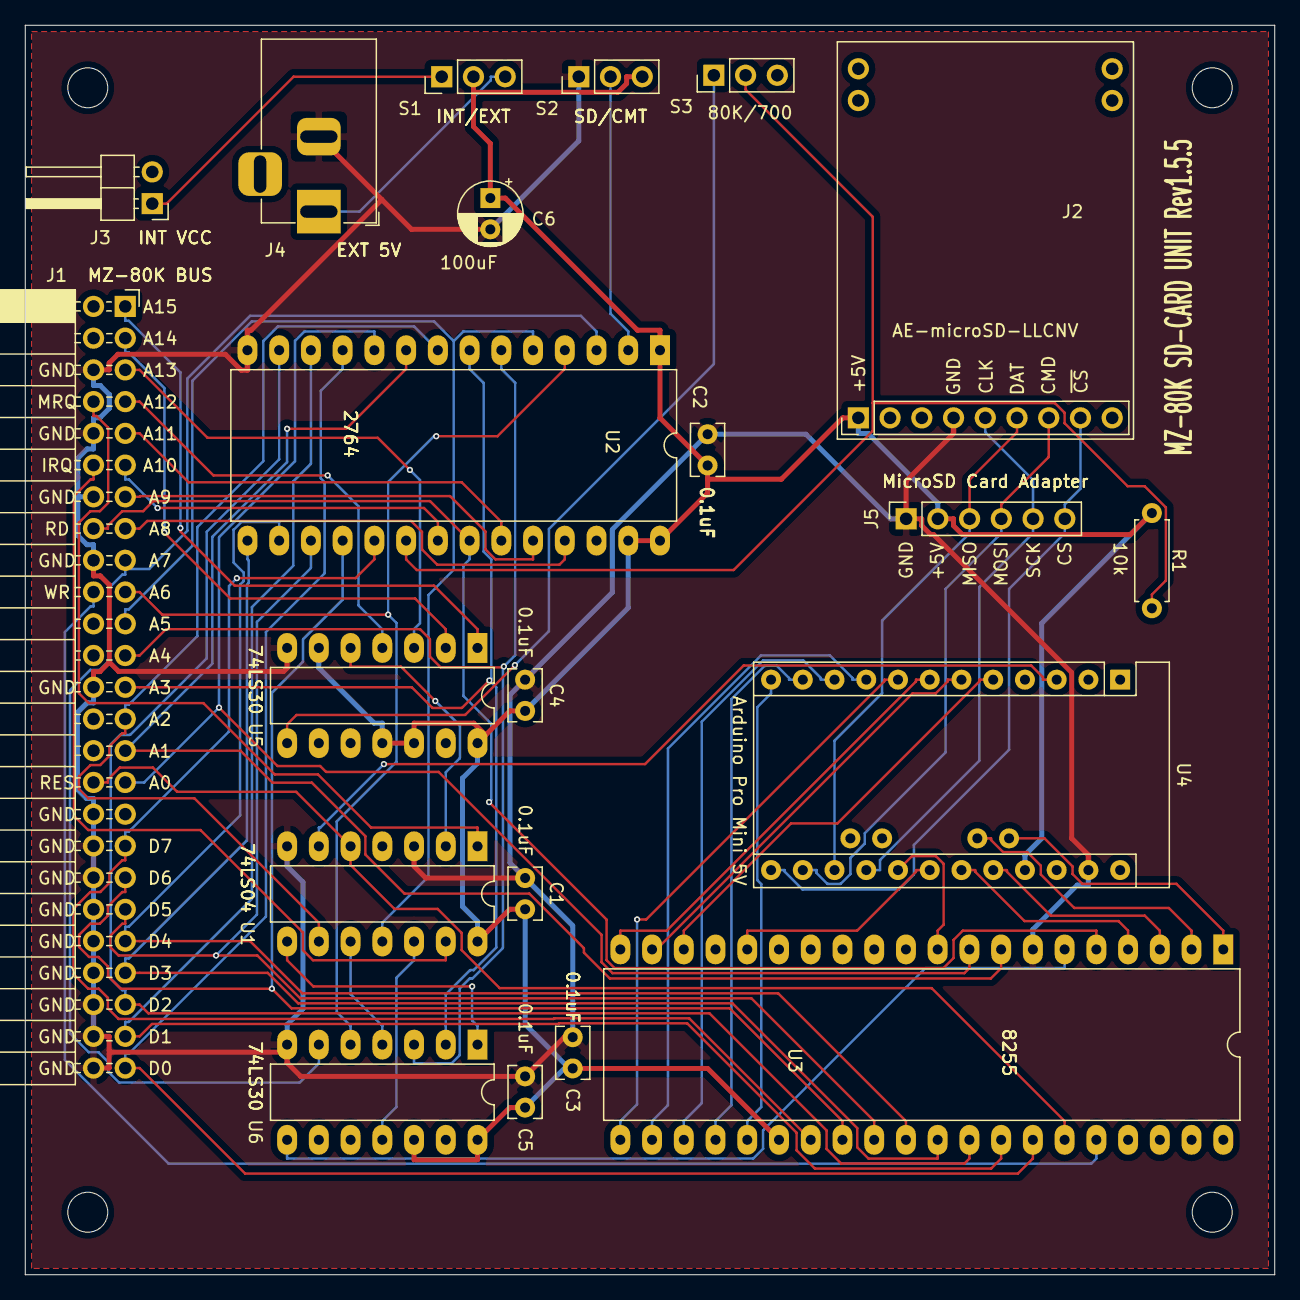
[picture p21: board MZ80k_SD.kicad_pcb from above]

Board: 2 copper layers, 100.0 x 100.0 mm, 25 parts (0 on the bottom side), 60 nets.

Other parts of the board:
MH1, MH2, MH3, MH4: MountingHole_3.2mm_M3

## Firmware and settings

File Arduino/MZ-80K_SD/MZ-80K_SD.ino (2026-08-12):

// 2022. 1.24 ファイルネームの後ろの20h詰めを0dhに修正するための処理をArduino側からMZ-80K側に修正
//           比較演算子の記述を見直し
// 2022. 1.25 各コマンド受信時のdelay()を廃止
// 2022. 1.26 FDコマンドでロード可能なファイル種類コードは0x01のみとしていた制限を撤廃
// 2022. 1.29 FDPコマンドのbug修正
// 2022. 1.30 FDLコマンド仕様変更 FDL A～Zの場合、ファイル名先頭一文字を比較して一致したものだけを出力
// 2022. 1.31 FDLコマンド仕様変更 FDL xの場合、ファイル名先頭一文字を比較して一致したものだけを出力
//            Bキーで前の20件を表示
// 2022. 2. 2 DOSファイル名がアルファベット小文字でもFDL xで検索できるように修正
// 2022. 2. 4 MZ-1200対策　初期化時にdelay(1000)を追加
// 2022. 2. 8 FDLコマンド仕様変更 FDL xの場合、ファイル名先頭1文字～32文字までに拡張
// 2023. 6.19 MZ-2000_SDの起動方式追加によりBOOT LOADER読み込みを追加。MZ-80K_SDには影響なし。
// 2024. 3. 4 sd-card再挿入時の初期化処理を追加
// 2025.12. 4 mon_ldata処理で不要なaddmztが入っていたため削除
// 2026. 8. 8 連番複数ファイルの多段ロード対応
// 2026. 8. 8 IFB、DATA、DATA…方式多段ロード対応
// 2026. 8. 9 IFB、ダミーヘッダ、DATA、ダミーヘッダ、DATA…方式多段ロード対応(本来要らないダミーヘッダがついたもの)
//            IFB、DATA、IFB、DATA…方式多段ロード対応(MZTファイルを単純にマージしたもの)
//
#include "SdFat.h"
#include <SPI.h>
SdFat SD;
unsigned long m_lop=128;
char m_name[40];
char k_name[40];
byte s_data[260];
char f_name[40];
char c_name[40];
char new_name[40];
int kflg=0;
unsigned long f_end;

#define CABLESELECTPIN  (10)
#define CHKPIN          (15)
#define PB0PIN          (2)
#define PB1PIN          (3)
#define PB2PIN          (4)
#define PB3PIN          (5)
#define PB4PIN          (6)
#define PB5PIN          (7)
#define PB6PIN          (8)
#define PB7PIN          (9)
#define FLGPIN          (14)
#define PA0PIN          (16)
#define PA1PIN          (17)
#define PA2PIN          (18)
#define PA3PIN          (19)
// ファイル名は、ロングファイルネーム形式対応
boolean eflg;

void sdinit(void){
  // SD初期化
  if( !SD.begin(CABLESELECTPIN,8) )
  {
////    Serial.println("Failed : SD.begin");
    eflg = true;
  } else {
////    Serial.println("OK : SD.begin");
    eflg = false;
  }
////    Serial.println("START");
}

void setup(){
////  Serial.begin(9600);
// CS=pin10
// pin10 output

  pinMode(CABLESELECTPIN,OUTPUT);
  pinMode( CHKPIN,INPUT);  //CHK
  pinMode( PB0PIN,OUTPUT); //送信データ
  pinMode( PB1PIN,OUTPUT); //送信データ
  pinMode( PB2PIN,OUTPUT); //送信データ
  pinMode( PB3PIN,OUTPUT); //送信データ
  pinMode( PB4PIN,OUTPUT); //送信データ
  pinMode( PB5PIN,OUTPUT); //送信データ
  pinMode( PB6PIN,OUTPUT); //送信データ
  pinMode( PB7PIN,OUTPUT); //送信データ
  pinMode( FLGPIN,OUTPUT); //FLG

  pinMode( PA0PIN,INPUT_PULLUP); //受信データ
  pinMode( PA1PIN,INPUT_PULLUP); //受信データ
  pinMode( PA2PIN,INPUT_PULLUP); //受信データ
  pinMode( PA3PIN,INPUT_PULLUP); //受信データ

  digitalWrite(PB0PIN,LOW);
  digitalWrite(PB1PIN,LOW);
  digitalWrite(PB2PIN,LOW);
  digitalWrite(PB3PIN,LOW);
  digitalWrite(PB4PIN,LOW);
  digitalWrite(PB5PIN,LOW);
  digitalWrite(PB6PIN,LOW);
  digitalWrite(PB7PIN,LOW);
  digitalWrite(FLGPIN,LOW);

// 2022. 2. 4 MZ-1200対策
  delay(1500);

  sdinit();
}

//4BIT受信
byte rcv4bit(void){
//HIGHになるまでループ
  while(digitalRead(CHKPIN) != HIGH){
  }
//受信
  byte j_data = digitalRead(PA0PIN)+digitalRead(PA1PIN)*2+digitalRead(PA2PIN)*4+digitalRead(PA3PIN)*8;
//FLGをセット
  digitalWrite(FLGPIN,HIGH);
//LOWになるまでループ
  while(digitalRead(CHKPIN) == HIGH){
  }
//FLGをリセット
  digitalWrite(FLGPIN,LOW);
  return(j_data);
}

//1BYTE受信
byte rcv1byte(void){
  byte i_data = 0;
  i_data=rcv4bit()*16;
  i_data=i_data+rcv4bit();
  return(i_data);
}

//1BYTE送信
void snd1byte(byte i_data){
//下位ビットから8ビット分をセット
  digitalWrite(PB0PIN,(i_data)&0x01);
  digitalWrite(PB1PIN,(i_data>>1)&0x01);
  digitalWrite(PB2PIN,(i_data>>2)&0x01);
  digitalWrite(PB3PIN,(i_data>>3)&0x01);
  digitalWrite(PB4PIN,(i_data>>4)&0x01);
  digitalWrite(PB5PIN,(i_data>>5)&0x01);
  digitalWrite(PB6PIN,(i_data>>6)&0x01);
  digitalWrite(PB7PIN,(i_data>>7)&0x01);
  digitalWrite(FLGPIN,HIGH);
//HIGHになるまでループ
  while(digitalRead(CHKPIN) != HIGH){
  }
  digitalWrite(FLGPIN,LOW);
//LOWになるまでループ
  while(digitalRead(CHKPIN) == HIGH){
  }
}

//小文字->大文字
char upper(char c){
  if('a' <= c && c <= 'z'){
    c = c - ('a' - 'A');
  }
  return c;
}

//多段ロードチェック「.mzt」を除いたファイル名の最後に「#?」(?=1～9)が付加されていれば多段ロード(kflg=1)
//                                  ファイル名の最後が「#」なら複数MZTファイルをマージしたmzt(kflg=2)
//                                  ファイル名の最後が「$」ならダミーヘッダ付き複合mzt(kflg=3)
void kchk(char *r_name,char *w_name){
  unsigned int lp1=0;

  strcpy(r_name,w_name);
  while (w_name[lp1] != 0x0D){
    lp1++;
  }
  kflg =0;
  if (w_name[lp1-7]=='#'){
    if (w_name[lp1-6]>='1' && w_name[lp1-6]<='9'){
      r_name[lp1-6] = w_name[lp1-6]+1;
//次番号のファイルが存在すれば継続ロードフラグ kflg=1
      if (SD.exists(k_name) == true){
        kflg=1;
      }
    }
  } else if (w_name[lp1-6]=='#'){
    kflg=2;
  } else if (w_name[lp1-6]=='$'){
    kflg=3;
  }
}

//ファイル名の最後が「.mzt」でなければ付加
void addmzt(char *w_name){
  unsigned int lp1=0;
  while (w_name[lp1] != 0x0D){
    lp1++;
  }
  if (w_name[lp1-4]!='.' ||
    ( w_name[lp1-3]!='M' &&
      w_name[lp1-3]!='m' ) ||
    ( w_name[lp1-2]!='Z' &&
      w_name[lp1-2]!='z' ) ||
    ( w_name[lp1-1]!='T' &&
      w_name[lp1-1]!='t' ) ){
         w_name[lp1++] = '.';
         w_name[lp1++] = 'm';
         w_name[lp1++] = 'z';
         w_name[lp1++] = 't';
  }
  w_name[lp1] = 0x00;
}

//SDカードにSAVE
void f_save(void){
char p_name[20];

//保存ファイルネーム取得
  for (unsigned int lp1 = 0;lp1 <= 32;lp1++){
    f_name[lp1] = rcv1byte();
  }
  addmzt(f_name);
//プログラムネーム取得
  for (unsigned int lp1 = 0;lp1 <= 16;lp1++){
    p_name[lp1] = rcv1byte();
  }
  p_name[15] =0x0D;
  p_name[16] =0x00;
//スタートアドレス取得
  int s_adrs1 = rcv1byte();
  int s_adrs2 = rcv1byte();
//スタートアドレス算出
  unsigned int s_adrs = s_adrs1+s_adrs2*256;
//エンドアドレス取得
  int e_adrs1 = rcv1byte();
  int e_adrs2 = rcv1byte();
//エンドアドレス算出
  unsigned int e_adrs = e_adrs1+e_adrs2*256;
//実行アドレス取得
  int g_adrs1 = rcv1byte();
  int g_adrs2 = rcv1byte();
//実行アドレス算出
  unsigned int g_adrs = g_adrs1+g_adrs2*256;
//ファイルサイズ算出
  unsigned int f_length = e_adrs - s_adrs + 1;
  unsigned int f_length1 = f_length % 256;
  unsigned int f_length2 = f_length / 256;
//ファイルが存在すればdelete
  if (SD.exists(f_name) == true){
    SD.remove(f_name);
  }
//ファイルオープン
  File file = SD.open( f_name, FILE_WRITE );
  if( true == file ){
//状態コード送信(OK)
    snd1byte(0x00);
//ファイルモード設定(01)
    file.write(char(0x01));
//プログラムネーム
    file.write(p_name);
    file.write(char(0x00));
//ファイルサイズ
    file.write(f_length1);
    file.write(f_length2);
//スタートアドレス
    file.write(s_adrs1);
    file.write(s_adrs2);
//実行アドレス
    file.write(g_adrs1);
    file.write(g_adrs2);
//7Fまで00埋め
    for (unsigned int lp1 = 0;lp1 <= 103;lp1++){
      file.write(char(0x00));
    }
//実データ
    long lp1 = 0;
    while (lp1 <= f_length-1){
      int i=0;
      while(i<=255 && lp1<=f_length-1){
        s_data[i]=rcv1byte();
        i++;
        lp1++;
      }
      file.write(s_data,i);
    }
    file.close();
   } else {
//状態コード送信(ERROR)
    snd1byte(0xF1);
    sdinit();
  }
}

//SDカードから読込
void f_load(void){
//ファイルネーム取得
  for (unsigned int lp1 = 0;lp1 <= 32;lp1++){
    m_name[lp1] = rcv1byte();
  }
  addmzt(m_name);
//多段ロードチェック
  kchk(k_name,m_name);
//ファイルが存在しなければERROR
  if (SD.exists(m_name) == true){
//ファイルオープン
    File file = SD.open( m_name, FILE_READ );
    if( true == file ){
//ファイル種類コードの判別を撤廃
//      if( file.read() == 0x01){
//状態コード送信(OK)
        snd1byte(0x00);
//DOSファイルのファイルサイズを更新
        f_end = file.size();
        int wk1 = 0;
        wk1 = file.read();
        for (unsigned int lp1 = 0;lp1 <= 16;lp1++){
          wk1 = file.read();
          snd1byte(wk1);
        }
//ファイルサイズ取得
        int f_length2 = file.read();
        int f_length1 = file.read();
        unsigned int f_length = f_length1*256+f_length2;
//スタートアドレス取得
        int s_adrs2 = file.read();
        int s_adrs1 = file.read();
        unsigned int s_adrs = s_adrs1*256+s_adrs2;
//実行アドレス取得
        int g_adrs2 = file.read();
        int g_adrs1 = file.read();
        unsigned int g_adrs = g_adrs1*256+g_adrs2;
        snd1byte(s_adrs2);
        snd1byte(s_adrs1);
        snd1byte(f_length2);
        snd1byte(f_length1);
        snd1byte(g_adrs2);
        snd1byte(g_adrs1);
        file.seek(128);
//データ送信
        for (unsigned int lp1 = 0;lp1 < f_length;lp1++){
            byte i_data = file.read();
            snd1byte(i_data);
        }
        file.close();
//ランチャーからのLOADでもIFB、DATA、DATAが正しく機能するように修正
        m_lop=128+f_length;
//ダミーヘッダ付きの場合ダミーヘッダは読み飛ばし
        if (kflg == 3) {
        m_lop=m_lop+128;
        }
//       } else {
//状態コード送信(ERROR)
//        snd1byte(0xF2);
          sdinit();
//      }  
     } else {
//状態コード送信(ERROR)
      snd1byte(0xFF);
      sdinit();
   }  
   } else {
//状態コード送信(FILE NOT FIND ERROR)
    snd1byte(0xF1);
    sdinit();
  }
}

//ASTART 指定されたファイルをファイル名「0000.mzt」としてコピー
void astart(void){
char w_name[]="0000.mzt";

//ファイルネーム取得
  for (unsigned int lp1 = 0;lp1 <= 32;lp1++){
    f_name[lp1] = rcv1byte();
  }
  addmzt(f_name);
//ファイルが存在しなければERROR
  if (SD.exists(f_name) == true){
//0000.mztが存在すればdelete
    if (SD.exists(w_name) == true){
      SD.remove(w_name);
    }
//ファイルオープン
    File file_r = SD.open( f_name, FILE_READ );
    File file_w = SD.open( w_name, FILE_WRITE );
      if( true == file_r ){
//実データ
        unsigned int f_length = file_r.size();
        long lp1 = 0;
        while (lp1 <= f_length-1){
          int i=0;
          while(i<=255 && lp1<=f_length-1){
            s_data[i]=file_r.read();
            i++;
            lp1++;
          }
          file_w.write(s_data,i);
        }
        file_w.close();
        file_r.close();
//状態コード送信(OK)
        snd1byte(0x00);
      } else {
//状態コード送信(ERROR)
      snd1byte(0xF1);
      sdinit();
    }
  } else {
//状態コード送信(ERROR)
    snd1byte(0xF1);
    sdinit();
  }  
}

// SD-CARDのFILELIST
void dirlist(void){
//比較文字列取得 32+1文字まで
  for (unsigned int lp1 = 0;lp1 <= 32;lp1++){
    c_name[lp1] = rcv1byte();
////  Serial.print(c_name[lp1],HEX);
////  Serial.println("");
  }
//
  File file = SD.open( "/" );
  File entry =  file.openNextFile();
  int cntl2 = 0;
  unsigned int br_chk =0;
  int page = 1;
//全件出力の場合には20件出力したところで一時停止、キー入力により継続、打ち切りを選択
  while (br_chk == 0) {
    if(entry){
      entry.getName(f_name,36);
      unsigned int lp1=0;
//一件送信
//比較文字列でファイルネームを先頭10文字まで比較して一致するものだけを出力
      if (f_match(f_name,c_name)){
        while (lp1<=36 && f_name[lp1]!=0x00){
        snd1byte(upper(f_name[lp1]));
        lp1++;
        }
        snd1byte(0x0D);
        snd1byte(0x00);
        cntl2++;
      }
    }
    if (!entry || cntl2 > 19){
//継続・打ち切り選択指示要求
      snd1byte(0xfe);

//選択指示受信(0:継続 B:前ページ 以外:打ち切り)
      br_chk = rcv1byte();
//前ページ処理
      if (br_chk==0x42){
//先頭ファイルへ
        file.rewindDirectory();
//entry値更新
        entry =  file.openNextFile();
//もう一度先頭ファイルへ
        file.rewindDirectory();
        if(page <= 2){
//現在ページが1ページ又は2ページなら1ページ目に戻る処理
          page = 0;
        } else {
//現在ページが3ページ以降なら前々ページまでのファイルを読み飛ばす
          page = page -2;
          cntl2=0;
          while(cntl2 < page*20){
            entry =  file.openNextFile();
//          if (upper(f_name[0]) == pg0 || pg0 == 0x20){
            if (f_match(f_name,c_name)){
              cntl2++;
            }
          }
        }
        br_chk=0;
      }
      page++;
      cntl2 = 0;
    }
//ファイルがまだあるなら次読み込み、なければ打ち切り指示
    if (entry){
      entry =  file.openNextFile();
    }else{
      br_chk=1;
    }
//FDLの結果が20件未満なら継続指示要求せずにそのまま終了
    if (!entry && cntl2 < 20 && page ==1){
      break;
    }
  }
//処理終了指示
  snd1byte(0xFF);
  snd1byte(0x00);
}

//f_nameとc_nameをc_nameに0x00が出るまで比較
//FILENAME COMPARE
boolean f_match(char *f_name,char *c_name){
  boolean flg1 = true;
  unsigned int lp1 = 0;
////  Serial.print(f_name);
////  Serial.print(" ");
////  Serial.print(c_name);
////  Serial.print(" ");
  while (lp1 <=32 && c_name[0] != 0x00 && flg1 == true){
////  Serial.print(f_name[lp1],HEX);
////  Serial.print("-");
////  Serial.print(c_name[lp1+1],HEX);
////  Serial.print(" ");
    if (upper(f_name[lp1]) != c_name[lp1+1]){
      flg1 = false;
    }
    lp1++;
    if (c_name[lp1+1]==0x00){
      break;
    }
  }
////  if (flg1){
////    Serial.println("true");
////  }else{
////    Serial.println("false");
////  }
  return flg1;
}

//FILE DELETE
void f_del(void){

//ファイルネーム取得
  for (unsigned int lp1 = 0;lp1 <= 32;lp1++){
    f_name[lp1] = rcv1byte();
  }
  addmzt(f_name);

//ファイルが存在しなければERROR
  if (SD.exists(f_name) == true){
//状態コード送信(OK)
    snd1byte(0x00);

//処理選択を受信(0:継続してDELETE 0以外:CANSEL)
    if (rcv1byte() == 0x00){
      if (SD.remove(f_name) == true){
//状態コード送信(OK)
        snd1byte(0x00);
      }else{
//状態コード送信(Error)
        snd1byte(0xf1);
        sdinit();
      }
    } else{
//状態コード送信(Cansel)
      snd1byte(0x01);
    }
  }else{
//状態コード送信(Error)
        snd1byte(0xf1);
        sdinit();
  }
}

//FILE RENAME
void f_ren(void){

//現ファイルネーム取得
  for (unsigned int lp1 = 0;lp1 <= 32;lp1++){
    f_name[lp1] = rcv1byte();
  }
  addmzt(f_name);

//ファイルが存在しなければERROR
  if (SD.exists(f_name) == true){
//状態コード送信(OK)
    snd1byte(0x00);

//新ファイルネーム取得
    for (unsigned int lp1 = 0;lp1 <= 32;lp1++){
      new_name[lp1] = rcv1byte();
    }
    addmzt(new_name);
//状態コード送信(OK)
    snd1byte(0x00);

    File file = SD.open( f_name, FILE_WRITE );
    if( true == file ){
      if (file.rename(new_name)){
 //状態コード送信(OK)
         snd1byte(0x00);
        } else {
 //状態コード送信(OK)
          snd1byte(0xff);
        }
      file.close();
    }else{
//状態コード送信(Error)
      snd1byte(0xf1);
      sdinit();
    }
  }else{
//状態コード送信(Error)
      snd1byte(0xf1);
      sdinit();
  }
}

//FILE DUMP
void f_dump(void){
unsigned int br_chk =0;

//ファイルネーム取得
  for (unsigned int lp1 = 0;lp1 <= 32;lp1++){
    f_name[lp1] = rcv1byte();
  }
  addmzt(f_name);

//ファイルが存在しなければERROR
  if (SD.exists(f_name) == true){
//状態コード送信(OK)
    snd1byte(0x00);

//ファイルオープン
    File file = SD.open( f_name, FILE_READ );
      if( true == file ){
//実データ送信(1画面:128Byte)
        unsigned int f_length = file.size();
        long lp1 = 0;
        while (lp1 <= f_length-1){
//画面先頭ADRSを送信
          snd1byte(lp1 % 256);
          snd1byte(lp1 / 256);
          int i=0;
//実データを送信
          while(i<128 && lp1<=f_length-1){
            snd1byte(file.read());
            i++;
            lp1++;
          }
//FILE ENDが128Byteに満たなかったら残りByteに0x00を送信
          while(i<128){
            snd1byte(0x00);
            i++;
          }
//指示待ち
          br_chk=rcv1byte();
//BREAKならポインタをFILE ENDとする
          if (br_chk==0xff){
            lp1 = f_length; 
          }
//B:BACKを受信したらポインタを256Byte戻す。先頭画面なら0に戻してもう一度先頭画面表示
          if (br_chk==0x42){
            if(lp1>255){
              if (lp1 % 128 == 0){
                lp1 = lp1 - 256;
              } else {
                lp1 = lp1 - 128 - (lp1 % 128);
              }
              file.seek(lp1);
            } else{
              lp1 = 0;
              file.seek(0);
            }
          }
        }
//FILE ENDもしくはBREAKならADRSに終了コード0FFFFHを送信
        if (lp1 > f_length-1){
          snd1byte(0xff);
          snd1byte(0xff);
        };
        file.close();
//状態コード送信(OK)
        snd1byte(0x00);
      } else {
//状態コード送信(ERROR)
      snd1byte(0xF1);
      sdinit();
    }
  }else{
//状態コード送信(Error)
        snd1byte(0xf1);
        sdinit();
  }
}

//FILE COPY
void f_copy(void){

//現ファイルネーム取得
  for (unsigned int lp1 = 0;lp1 <= 32;lp1++){
    f_name[lp1] = rcv1byte();
  }
  addmzt(f_name);
//ファイルが存在しなければERROR
  if (SD.exists(f_name) == true){
//状態コード送信(OK)
    snd1byte(0x00);

//新ファイルネーム取得
    for (unsigned int lp1 = 0;lp1 <= 32;lp1++){
      new_name[lp1] = rcv1byte();
    }
    addmzt(new_name);
//新ファイルネームと同じファイルネームが存在すればERROR
    if (SD.exists(new_name) == false){
//状態コード送信(OK)
        snd1byte(0x00);
//ファイルオープン
    File file_r = SD.open( f_name, FILE_READ );
    File file_w = SD.open( new_name, FILE_WRITE );
      if( true == file_r ){
//実データコピー
        unsigned int f_length = file_r.size();
        long lp1 = 0;
        while (lp1 <= f_length-1){
          int i=0;
          while(i<=255 && lp1<=f_length-1){
            s_data[i]=file_r.read();
            i++;
            lp1++;
          }
          file_w.write(s_data,i);
        }
        file_w.close();
        file_r.close();
//状態コード送信(OK)
        snd1byte(0x00);
      }else{
//状態コード送信(Error)
      snd1byte(0xf1);
      sdinit();
    }
      }else{
//状態コード送信(Error)
        snd1byte(0xf3);
        sdinit();
    }
  }else{
//状態コード送信(Error)
      snd1byte(0xf1);
      sdinit();
  }
}

//91hで0436H MONITOR ライト インフォメーション代替処理
void mon_whead(void){
char m_info[130];
//インフォメーションブロック受信
  for (unsigned int lp1 = 0;lp1 < 128;lp1++){
    m_info[lp1] = rcv1byte();
  }
//S-OS SWORDからは最後が20hのファイルネームが送られて来るため0dhを付加
//8080用テキスト・エディタ＆アセンブラからファイルネームの後ろに20hが送られて来るため0dhに修正
//MZ-80K側で対処
//  int lp2 = 17;
//  while (lp2>0 && (m_info[lp2] ==0x20 || m_info[lp2] ==0x0d)){
//    m_info[lp2]=0x0d;
//    lp2--;
//  }
//ファイルネーム取り出し
  for (unsigned int lp1 = 0;lp1 < 17;lp1++){
    m_name[lp1] = m_info[lp1+1];
  }
//DOSファイルネーム用に.MZTを付加
  addmzt(m_name);
  m_info[16] = 0x0d;
//ファイルが存在すればdelete
  if (SD.exists(m_name) == true){
    SD.remove(m_name);
  }
//ファイルオープン
  File file = SD.open( m_name, FILE_WRITE );
  if( true == file ){
//状態コード送信(OK)
    snd1byte(0x00);
//インフォメーションブロックwrite
    for (unsigned int lp1 = 0;lp1 < 128;lp1++){
      file.write(m_info[lp1]);
    }
    file.close();
  } else {
//状態コード送信(ERROR)
    snd1byte(0xF1);
    sdinit();
  }
}

//92hで0475H MONITOR ライト データ代替処理
void mon_wdata(void){
//ファイルサイズ取得
  int f_length1 = rcv1byte();
  int f_length2 = rcv1byte();
//ファイルサイズ算出
  unsigned int f_length = f_length1+f_length2*256;
//ファイルオープン
  File file = SD.open( m_name, FILE_WRITE );
  if( true == file ){
//状態コード送信(OK)
    snd1byte(0x00);
//実データ
    long lp1 = 0;
    while (lp1 <= f_length-1){
      int i=0;
      while(i<=255 && lp1<=f_length-1){
        s_data[i]=rcv1byte();
        i++;
        lp1++;
      }
      file.write(s_data,i);
    }
    file.close();
  } else {
//状態コード送信(ERROR)
    snd1byte(0xF1);
  }
}

//04D8H MONITOR リード インフォメーション代替処理
void mon_lhead(void){
//リード データ POINTクリア
  m_lop=128;
//ファイルネーム取得
  for (unsigned int lp1 = 0;lp1 <= 32;lp1++){
    m_name[lp1] = rcv1byte();
  }
  addmzt(m_name);
//多段ロードチェック
  kchk(k_name,m_name);
//ファイルが存在しなければERROR
  if (SD.exists(m_name) == true){
    snd1byte(0x00);
//ファイルオープン
    File file = SD.open( m_name, FILE_READ );
    if( true == file ){
      snd1byte(0x00);
//DOSファイルのファイルサイズを更新
      f_end = file.size();
      for (unsigned int lp1 = 0;lp1 < 128;lp1++){
          byte i_data = file.read();
          snd1byte(i_data);
      }
      file.close();
      snd1byte(0x00);
    } else {
//状態コード送信(ERROR)
      snd1byte(0xFF);
      sdinit();
    }  
  } else {
//状態コード送信(FILE NOT FIND ERROR)
    snd1byte(0xF1);
    sdinit();
  }
}
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
void loop()
{
  digitalWrite(PB0PIN,LOW);
  digitalWrite(PB1PIN,LOW);
  digitalWrite(PB2PIN,LOW);
  digitalWrite(PB3PIN,LOW);
  digitalWrite(PB4PIN,LOW);
  digitalWrite(PB5PIN,LOW);
  digitalWrite(PB6PIN,LOW);
  digitalWrite(PB7PIN,LOW);
  digitalWrite(FLGPIN,LOW);
//コマンド取得待ち
////  Serial.print("cmd:");
  byte cmd = rcv1byte();
////  Serial.println(cmd,HEX);
  if (eflg == false){
    switch(cmd) {
//80hでSDカードにsave
      case 0x80:
////  Serial.println("SAVE START");
//状態コード送信(OK)
        snd1byte(0x00);
        f_save();
        break;
//81hでSDカードからload
      case 0x81:
////  Serial.println("LOAD START");
//状態コード送信(OK)
        snd1byte(0x00);
        f_load();
        break;
//82hで指定ファイルを0000.mztとしてリネームコピー
      case 0x82:
////  Serial.println("ASTART START");
//状態コード送信(OK)
        snd1byte(0x00);
        astart();
        break;
//83hでファイルリスト出力
      case 0x83:
////  Serial.println("FILE LIST START");
//状態コード送信(OK)
        snd1byte(0x00);
        sdinit();
        dirlist();
        break;
//84hでファイルDelete
      case 0x84:
////  Serial.println("FILE Delete START");
//状態コード送信(OK)
        snd1byte(0x00);
        f_del();
        break;
//85hでファイルリネーム
      case 0x85:
////  Serial.println("FILE Rename START");
//状態コード送信(OK)
        snd1byte(0x00);
        f_ren();
        break;
      case 0x86:  
//86hでファイルダンプ
////  Serial.println("FILE Dump START");
//状態コード送信(OK)
        snd1byte(0x00);
        f_dump();
        break;
      case 0x87:  
//87hでファイルコピー
////  Serial.println("FILE Copy START");
//状態コード送信(OK)
        snd1byte(0x00);
        f_copy();
        break;
      case 0x91:
//91hで0436H MONITOR ライト インフォメーション代替処理
////  Serial.println("0436H START");
//状態コード送信(OK)
        snd1byte(0x00);
        mon_whead();
        break;
//92hで0475H MONITOR ライト データ代替処理
      case 0x92:
////  Serial.println("0475H START");
//状態コード送信(OK)
        snd1byte(0x00);
        mon_wdata();
        break;
//93hで04D8H MONITOR リード インフォメーション代替処理
      case 0x93:
////  Serial.println("04D8H START");
//状態コード送信(OK)
        snd1byte(0x00);
        mon_lhead();
        break;
//94hで04F8H MONITOR リード データ代替処理
      case 0x94:
////  Serial.println("04F8H START");
//状態コード送信(OK)
        snd1byte(0x00);
        mon_ldata();
        break;
//95hでBOOT LOAD(MZ-2000_SD専用)
      case 0x95:
////  Serial.println("BOOT LOAD START");
//状態コード送信(OK)
        snd1byte(0x00);
        boot();
        break;
//96hで継続ロードCHECK
      case 0x96:
////  Serial.println("KFLG CHECK");
//状態コード送信(OK)
        snd1byte(0x00);
        kflgchk();
        break;
      default:
//状態コード送信(CMD ERROR)
        snd1byte(0xF4);
    }
  } else {
//状態コード送信(ERROR)
    snd1byte(0xF0);
    sdinit();
  }
}
